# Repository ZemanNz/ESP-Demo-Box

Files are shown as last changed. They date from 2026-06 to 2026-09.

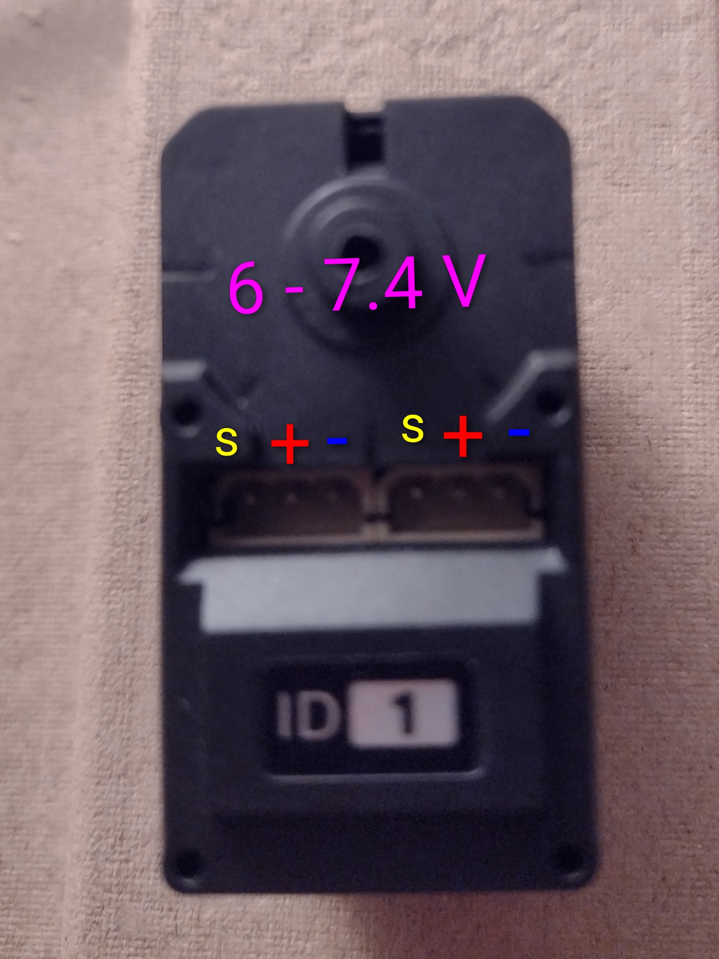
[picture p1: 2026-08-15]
documentation/ss_popis.jpg

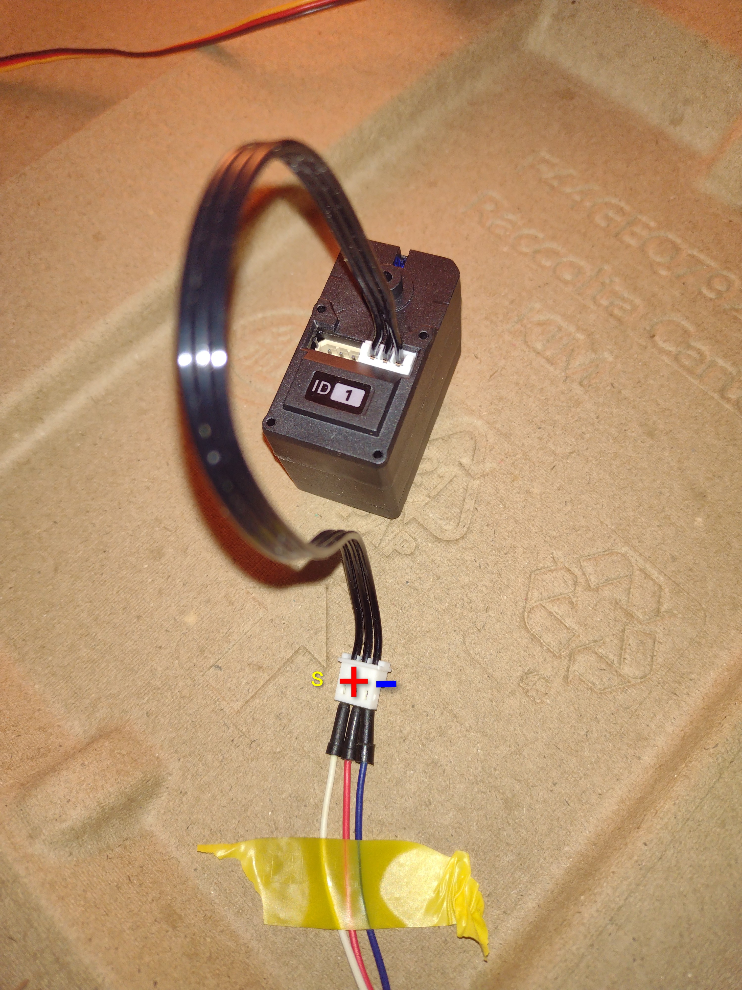
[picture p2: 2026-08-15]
documentation/zap_ss.jpg

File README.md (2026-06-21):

# ESP-Demo-Box

Tento projekt obsahuje kompletní podklady pro vývoj a konstrukci zařízení **ESP-Demo-Box**. Projekt je rozdělen do několika hlavních částí:

## Struktura projektu

- **`documentation/`**: Uživatelská a technická dokumentace k projektu.
- **`firmware/`**: Zdrojové kódy pro mikrokontroléry (PlatformIO projekty pro desky ESP32-S3).
  - **`horni_panel/`**: Firmware pro horní panel.
  - **`spodni_panel/`**: Firmware pro spodní panel.
- **`hardware/`**: Podklady pro výrobu a konstrukci.
  - **`3D/`**: 3D modely pro tisk.
  - **`Ele/`**: Schémata zapojení a plošné spoje.

## Vývoj (Firmware)

Firmware je vyvíjen v prostředí **PlatformIO** (ideálně jako rozšíření pro VS Code).

### Požadavky
- [VS Code](https://code.visualstudio.com/) s nainstalovaným rozšířením [PlatformIO IDE](https://platformio.org/platformio-ide).

### Otevření a kompilace
1. Otevřete konkrétní složku projektu ve `firmware/` (např. `horni_panel` nebo `spodni_panel`) v VS Code.
2. PlatformIO automaticky stáhne potřebné závislosti a nástroje pro ESP32-S3.
3. Pro sestavení projektu použijte tlačítko **Build** (ikonka zaškrtnutí) v dolní liště PlatformIO.
4. Pro nahrání firmwaru připojte desku přes USB a klikněte na **Upload** (ikonka šipky).

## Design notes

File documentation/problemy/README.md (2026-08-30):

# Dokumentace problémů a jejich řešení – Maturitní projekt ESP-Demo-Box

Tato složka slouží jako přehledný registr technických problémů, na které jsme narazili během vývoje firmware a hardware pro maturitní projekt ESP-Demo-Box, a detailní popis jejich řešení.

## Seznam zdokumentovaných problémů

| ID | Název problému / Téma | Oblast | Odkaz na detailní popis |
| :--- | :--- | :--- | :--- |
| **01** | Problikávání TFT displeje ST7789 při vykreslování her | Grafika / SPI displej | [Zobrazit řešení (Double Buffering)](problikavani_displeje_double_buffering.md) |
| **02** | Zarovnání paměti v binárním UART protokolu (Memory Padding) | Komunikace / Paměť | [Zobrazit řešení (#pragma pack)](01_zarovnani_pameti_pragma_pack.md) |
| **03** | Zabezpečení integrity dat a rušení od motorů (XOR Checksum) | Komunikace / EMI | [Zobrazit řešení (XOR Checksum)](02_integrita_dat_xor_checksum.md) |
| **04** | Konflikt autority řízení servomotorů v distribuovaném systému | Řízení / Robotika | [Zobrazit rozbor (Authority Race)](03_konflikt_autority_rizeni_serv.md) |
| **05** | Hybridní UART přenos (Okamžitá změna + Záchranný Heartbeat) | Komunikace / FreeRTOS | [Zobrazit řešení (Hybridní přenos)](04_hybridni_uart_prenos_heartbeat.md) |
| **06** | Oddělení datového stavu a fyzických ovladačů (Architecture) | Architektura C++ | [Zobrazit řešení (SystemState vs SensorManager)](05_oddeleni_systemstate_a_sensormanager.md) |
| **07** | Řízení periferií dolního panelu čistě přes virtuální stav | Architektura / Abstrakce | [Zobrazit řešení (Virtuální stav)](06_rizeni_dolniho_panelu_pres_virtualni_stav.md) |
| **08** | Architektura Master-Slave mezi dvěma mikrokontroléry ESP32 | Systémový návrh | [Zobrazit rozbor (Master-Slave ESP32)](07_architektura_master_slave_esp32.md) |
| **09** | Úsporný režim Light Sleep a asynchronní probouzení (Wake-up) | Power Management / HW | [Zobrazit řešení (Light Sleep)](08_usporny_rezim_light_sleep_a_wake_up.md) |
| **10** | Vkládání webu do Flash paměti (`PROGMEM`), HTTP Caching a trvalá paměť | Web / Síť / Paměť | [Zobrazit řešení (PROGMEM & HTTP Caching)](09_vkladani_webu_do_progmem_a_http_caching.md) |

---
*Všechny dokumenty obsahují detailní technické zdůvodnění, matematické a paměťové souvislosti a zdrojové kódy přímo použitelné do textové části maturitní práce.*

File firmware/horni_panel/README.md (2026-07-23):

# Horní senzorový panel – ESP32-S3 Firmware
**Maturitní projekt | ESP32-S3 DevKitC (44 pinů) | PlatformIO + Arduino Framework**

Tento projekt obsahuje plně modulární, produkčně laděný firmware pro **Horní senzorový panel** předváděcího demo boxu. Všechny moduly jsou řízeny přes konfigurační makra (`#define ENABLE_*`) v souboru `include/config.h` a běží v neblokující smyčce `loop()` s přesným časováním `millis()`.

---

## 🚀 Stav vývoje a testování
> **Dnešní stav (23. 7. 2026):**  
> Všechny moduly byly odzkoušeny, zkompilovány a **úspěšně nahrány a ověřeny na reálném hardwaru ESP32-S3 DevKitC**. Systém běží stabilně, bez pádu procesoru i bez zásahů Task Watchdog Timeru (`TG1WDT_SYS_RST`).

---

## 🛠️ Funkcionalita a součinnost modulů

1. **Barevná interakce (TCS34725 ➔ WS2812B LED pásek)**:
   - Senzor **TCS34725** načítá RGB složky přiloženého objektu.
   - Pásek **WS2812B (8 RGB LED)** dynamicky zrcadlí naměřenou barvu v reálném čase.
2. **Duální I2C sběrnice (Vyřešení kolize adres 0x29)**:
   - `I2C_0` (Wire, SDA: 8, SCL: 9): Řídí **LSM6DS3** (0x6A), **LCD1602** (0x27) a **VL53L0X** (0x29).
   - `I2C_1` (Wire1, SDA: 5, SCL: 6): Samostatná sběrnice pro **TCS34725** (0x29) zamezuje konfliktům adres.
3. **Měření vzdálenosti a překážek**:
   - **VL53L0X**: Přesné laserové měření vzdálenosti v milimetrech přes I2C_0.
   - **HC-SR04**: Ultrazvukové měření vzdálenosti v centimetrech (TRIG = GPIO 4, ECHO = GPIO 18).
   - **IR Senzor 1**: Digitální detekce překážek na GPIO 38 (LOW = detekce).
4. **Zobrazení dat**:
   - **2.8" TFT ST7789** (SPI): Střídá 3 grafické obrazovky (Senzory, Vzdálenost, Uptime).
   - **LCD 1602 I2C**: Zobrazuje aktuální teplotu a vlhkost ze senzoru DHT11.
   - **74HC595 Sedmisegment**: Bit-banging čítač 0–999 na 3 číslicích (DATA = 15, CLK = 16, LATCH = 17).
5. **Orientační senzor**:
   - **LSM6DS3**: Gyroskop a akcelerometr s automatickou klidovou kalibrací offsetu při startu (výpočet Roll, Pitch, Yaw).
6. **Zvuková a vizuální odezva**:
   - **Pasivní bzučák**: Zvuková znělka při startu + krátké pípnutí každých 5 sekund.
   - **DHT11**: Teplotní a vlhkostní senzor na GPIO 3.

---

## 📌 Kompletní mapa zapojení pinů (ESP32-S3)

| Zařízení / Modul | Signál | ESP32-S3 GPIO | Poznámka |
| :--- | :--- | :--- | :--- |
| **DHT11** | DATA | **GPIO 3** | Teplota & Vlhkost (4k7 pull-up) |
| **HC-SR04** | TRIG | **GPIO 4** | Ultrazvuk Trigger |
| **HC-SR04** | ECHO | **GPIO 18** | Ultrazvuk Echo *(mimo USB piny)* |
| **IR Senzor 1** | OUT | **GPIO 38** | Detekce překážky *(mimo Octal Flash)* |
| **WS2812B** | DATA | **GPIO 42** | 8 RGB LED *(Adafruit_NeoPixel)* |
| **Bzučák** | Vstup | **GPIO 7** | Pasivní bzučák |
| **74HC595** | DS (DATA) | **GPIO 15** | Sedmisegmentová sériová data |
| **74HC595** | SH_CP (CLK)| **GPIO 16** | Sedmisegmentové hodiny |
| **74HC595** | ST_CP (LATCH)| **GPIO 17** | Sedmisegmentový Latch |
| **TFT 2.8"** | CS | **GPIO 10** | Chip Select |
| **TFT 2.8"** | SDI (MOSI) | **GPIO 11** | Hardware SPI Data |
| **TFT 2.8"** | SCK | **GPIO 12** | Hardware SPI Clock |
| **TFT 2.8"** | DC | **GPIO 13** | Data / Command |
| **TFT 2.8"** | RESET | **GPIO 14** | Reset displeje |
| **TFT 2.8"** | LED | **GPIO 21** / 3.3V | Podsvícení |
| **I2C_0 (Wire)** | SDA / SCL | **GPIO 8 / GPIO 9** | LSM6DS3, LCD1602, VL53L0X |
| **I2C_1 (Wire1)**| SDA / SCL | **GPIO 5 / GPIO 6** | TCS34725 (0x29) |
| **Fotorezistory**| IN1 / IN2 | **GPIO 1 / GPIO 2** | Analogové fotorezistory |
| **Tlačítka** | BTN1 / BTN2 | **GPIO 47 / GPIO 48** | INPUT_PULLUP |

### ⚠️ Vyhrazené piny (Nepoužívat pro I/O!):
- **GPIO 19, 20**: Vnitřně vyhrazeno pro rozhraní **USB D- / D+**.
- **GPIO 33, 34, 35, 36, 37**: Vnitřně vyhrazeno pro paměťovou sběrnici **Octal Flash / OPI PSRAM** na ESP32-S3 N16R8.

---

## ⚙️ Kompilace a nahrání (PlatformIO)

 Sestavení projektu:
```bash
pio run -e demo_panel
```

 Nahrání do ESP32-S3:
```bash
pio run -e demo_panel -t upload --upload-port /dev/ttyUSB0
```

 Sériový monitor (115200 baud):
```bash
pio device monitor -b 115200
```

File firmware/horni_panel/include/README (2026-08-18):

# Horní senzorový panel – Zapojení hardwaru
**ESP32-S3 DevKitC (44 pinů) | Maturitní projekt**

Tento soubor obsahuje **aktuální a přesnou** mapu zapojení všech modulů.
Všechny definice pinů odpovídají souboru `config.h` a `demo_panel.cpp`.

---

## Povolení / zakázání modulů

V souboru `config.h` lze jednotlivé moduly zapínat nebo vypínat odkomentováním/zakomentováním příslušného `#define ENABLE_*`.

---

## 1. Digitální senzory

| Zařízení | ESP32 GPIO | Poznámka / Nastavení |
|---|---|---|
| **DHT11 DATA** | GPIO **3** | Teplota & vlhkost (4k7 pull-up na 3.3 V) |
| **HC-SR04 TRIG** | GPIO **4** | Ultrazvuk – Trigger pulz (10 µs HIGH) |
| **HC-SR04 ECHO** | GPIO **18**  | Ultrazvuk – Echo vstup (3.3 V logic) |
| **IR Senzor 1**  | GPIO **38**  | Digitální detekce překážky (LOW = detekce)  |
| **LSM6DS3 INT1** | GPIO **45**  | Přerušení akcelerometru pro probuzení otřesem (GPIO 45) |
| **Tlačítko 1** | GPIO **47**  | INPUT_PULLUP (GND při stisku) |
| **Tlačítko 2** | GPIO **48**  | INPUT_PULLUP (Reset desky) |

---

## 2. Analogové vstupy

| Zařízení | ESP32 GPIO | Poznámka |
|---|---|---|
| Fotorezistor 1 | GPIO **1** | ADC1, napěťový dělič  |
| Fotorezistor 2 | GPIO **2** | ADC1, napěťový dělič  |

---

## 3. Výstupy & LED

| Zařízení | ESP32 GPIO | Poznámka |
|---|---|---|
| **Pasivní bzučák**| GPIO **7** | tone() – tranzistorový spínač |
| **LED 1** | GPIO **39**| Rezistor 220 Ω |
| **LED 2** | GPIO **40**| Rezistor 220 Ω |
| **LED 3** | GPIO **41**| Rezistor 220 Ω |
| **WS2812B DATA**  | GPIO **42**| 8 RGB LED pásek (Adafruit_NeoPixel) |

---

## 4. 74HC595 – Sedmisegmentový displej (3 číslice, bit-banging)

Displej se Společnou Anodou (`SEG_COMMON_ANODE = true`).

| Signál | HC595 pin | ESP32 GPIO  |
|---|---|---|
| DS (DATA) | pin 14 | GPIO **15** |
| SH_CP (CLK) | pin 11 | GPIO **16** |
| ST_CP (LATCH) | pin 12 | GPIO **17** |
| OE (Enable) | pin 13 | GND |
| MR (Reset) | pin 10 | 3.3 V |

---

## 5. TFT 2.8" displej (ILI9341 / ST7789, SPI)

Knihovna: `Adafruit_ST7789` | Rozlišení: 240×320 (landscape 320×240)

Presné názvy pinů podle potisku na displeji (shodné s `examples/2.8_tft_display/README.md`):

| Displej Pin (Potisk) | ESP32-S3 GPIO | Popis signálu |
| --- | --- | --- |
| **VCC** | `5V` | Napájení displeje |
| **GND** | `GND` | Společná zem |
| **CS** | `GPIO 10` | Chip Select (výběr SPI čipu) |
| **RESET** | `GPIO 14` | Reset displeje |
| **DC** | `GPIO 13` | Data / Command (příkazový signál) |
| **SDI (MOSI)** | `GPIO 11` | Hardware SPI Data (Master Out Slave In) |
| **SCK** | `GPIO 12` | Hardware SPI Clock (hodiny) |
| **LED** | `3.3V` / `GPIO 21` | Podsvícení displeje (trvale 3.3 V nebo GPIO 21) |
| **SDO (MISO)** | *Nezapojeno*  | MISO / Dotyková vrstva (nevyužito) |

---

## 6. I2C sběrnice (Dvou-sběrnicový systém pro zamezení kolizí)

### I2C_0 – Hlavní sběrnice (Wire)
| Zařízení | Adresa | ESP32 GPIO |
|---|---|---|
| LSM6DS3 (gyro) | 0x6A | SDA: **8**, SCL: **9** |
| LCD 1602 (PCF8574)| 0x27 | SDA: **8**, SCL: **9** |
| VL53L0X (laser) | 0x29 | SDA: **8**, SCL: **9** |

### I2C_1 – Sekundární sběrnice (Wire1)
Důvod: TCS34725 má adresu 0x29, která by kolidovala s VL53L0X.
| Zařízení | Adresa | ESP32 GPIO |
|---|---|---|
| TCS34725 (barva)  | 0x29 | SDA: **5**, SCL: **6** |

---

## 7. UART1 – Komunikace s druhým ESP32

| Signál | ESP32 GPIO  |
|---|---|
| TX (výstup) | GPIO **17** |
| RX (vstup)  | GPIO **18** |

*(Baudrate: 115200, 8N1. Pozn: GPIO 17/18 lze sdílet pokud je UART1 vypnutý).*

---

## 8. Kompletní tabulka GPIO pinů (Quick Reference)

| GPIO | Připojené zařízení / Funkce | GPIO | Připojené zařízení / Funkce |
|---|---|---|---|
| **1**| Fotorezistor 1 | **21**| TFT podsvícení (BL) |
| **2**| Fotorezistor 2 | **38**| IR Senzor 1 |
| **3**| DHT11 DATA | **39**| LED 1 |
| **4**| HC-SR04 TRIG | **40**| LED 2 |
| **5**| I2C1 SDA (TCS34725) | **41**| LED 3 |
| **6**| I2C1 SCL (TCS34725) | **42**| WS2812B RGB pásek |
| **7**| Bzučák | **43**| UART0 TX (Serial Monitor) |
| **8**| I2C0 SDA | **44**| UART0 RX (Serial Monitor) |
| **9**| I2C0 SCL | **47**| Tlačítko 1 |
| **10**| TFT CS (Chip Select) | **48**| Tlačítko 2 / Reset |
| **11**| TFT SDI / MOSI (Data) | | |
| **12**| TFT SCK (Hodiny) | | |
| **13**| TFT DC (Data/Command) | | |
| **14**| TFT RESET | | |
| **15**| 74HC595 DATA | | |
| **16**| 74HC595 CLK | | |
| **17**| 74HC595 LATCH / UART1 TX | | |
| **18**| HC-SR04 ECHO / UART1 RX | | |

---

## ⚠️ Důležitá varování pro ESP32-S3 N16R8:

1. **GPIO 19 a 20 (NEPOUŽÍVAT)**: Vnitřně vyhrazeny pro USB D- a D+. Použití pro běžné I/O způsobí zamrznutí nebo zablokování nahrávání.
2. **GPIO 33, 34, 35, 36, 37 (NEPOUŽÍVAT)**: Vnitřně vyhrazeny pro Octal Flash/PSRAM paměťovou sběrnici. Příkaz `pinMode()` na těchto pinech způsobí okamžitý pády/reset procesoru (`TG1WDT_SYS_RST`).

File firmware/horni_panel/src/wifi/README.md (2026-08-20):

# Jednoduchý průvodce Wi-Fi a Webem (ESP-Demo-Box)

Tento návod ti **lidsky, jednoduše a názorně** vysvětlí, jak celá bezdrátová část v našem Demo-Boxu funguje. Nemusíš být síťový expert – vše je vysvětleno na praktických přirovnáních a na reálném fungování kódu krok za krokem.

---

## 1. Co to celé dělá a jak to funguje v praxi?

Představ si, že přijdeš k hotovému Demo-Boxu:
1. **ESP32 se zapne** a začne se chovat jako malý **Wi-Fi router** (vysílá vlastní Wi-Fi síť s názvem `ESP-Demo-Box`).
2. Ty vezmeš telefon a **fotoaparátem naskenuješ QR kód** na krabičce.
3. Mobil se **bez zadávání hesla připojí**.
4. Během vteřiny mobilu **automaticky vyskočí okno s naším webem** (díky funkci *Captive Portal* – stejně jako když se připojuješ na Wi-Fi v hotelu nebo ve vlaku).
5. Na mobilu vidíš **živé hodnoty ze všech senzorů** (teplota, vzdálenosti, gyroskop, tlačítka) a můžeš prstem **hýbat servy, motorem, rozsvěcet LEDky nebo přepínat hry na displeji**.

---

## 2. Kde co běží? (Backend vs. Frontend)

Aby ses v tom neztratil, musíme si rozdělit svět na dvě části:

```
+------------------------------------+          +------------------------------------+
|       ESP32-S3 (BACKEND)           |          |     MOBILNÍ TELEFON (FRONTEND)     |
|                                    |          |                                    |
| - Běží v čipu v krabičce (Core 0)  |  Wi-Fi   | - Běží v prohlížeči v mobilu       |
| - Kód: WebManager.h a .cpp         | <======> | - Kód: HTML, CSS, JavaScript       |
| - Nemá webový prohlížeč!           | WebSocket| - Zobrazuje tlačítka a barvy       |
| - Stará se o senzory, serva a motory|         | - Počítá dotyky prstů uživatele    |
+------------------------------------+          +------------------------------------+
```

1. **Backend (ESP32 / `WebManager.cpp`):**
   * Běží fyzicky v mikrokontroléru ESP32-S3 na **Core 0**.
   * Nemá žádný prohlížeč ani vykreslovací grafickou kartu pro web.
   * Jeho úkolem je vysílat Wi-Fi signál, přijímat příkazy a starat se o hardware (číst fyzické senzory, hýbat servy a ovládat motory).

2. **Frontend (Mobilní telefon / `index.html`, `style.css`, `script.js`):**
   * Webový kód je sice zkompilovaný a uložený ve Flash paměti ESP32 (`WebPages.h`), ale **ESP32 ho sama nespouští**.
   * Jakmile se mobil připojí, ESP32 pošle tento text přes Wi-Fi do mobilu.
   * **Teprve webový prohlížeč v mobilu** (Safari nebo Chrome) tento kód zpracuje, nakreslí hezká tlačítka a spustí JavaScript. Všechny animace a barvy tak počítá procesor tvého telefonu!

---

## 3. Hlavní pojmy a síťové základy vysvětlené „po lopatě“

### 🚪 A) Co je to HTTP port (Port 80) a DNS port (Port 53)?
Představ si IP adresu (`192.168.4.1`) jako **adresu panelového domu**:
* Aby pošťák věděl, do kterých konkrétních dveří v domě má jít, potřebuje **číslo bytu = PORT**.
* Na jedné IP adrese může běžet více různých síťových služeb, a každá naslouchá u svých vlastních dveří:
  * **Port 80 (HTTP):** Dveře vyhrazené pro webové stránky. Když do prohlížeče napíšeš IP adresu, prohlížeč automaticky klepe na dveře číslo 80.
  * **Port 53 (DNS):** Dveře vyhrazené pro překladač doménových jmen.

---

### 🌐 B) Co je to DNS server (Port 53) a jak funguje Captive Portal?
* **Jak funguje běžný internet:** Když v mobilu napíšeš `seznam.cz`, mobil se zeptá DNS serveru na portu 53: *"Jaká je IP adresa pro seznam.cz?"* DNS server odpoví: `77.75.77.222`.
* **Náš trik (Fake DNS na ESP32):** Naše ESP32 má spuštěný vlastní DNS server na portu 53 (`dnsServer.start(53, "*", "192.168.4.1")`).
* Když se mobil připojí k síti `ESP-Demo-Box`, okamžitě na pozadí zkouší posílat DNS dotazy na internet (zkoumá, zda funguje síť).
* Náš DNS server na **jakýkoliv dotaz z mobilu odpoví: `192.168.4.1`**.
* Mobilní telefon si myslí: *"Aha, tohle je síť v hotelu nebo ve vlaku, kde se musím nejprve přihlásit!"* a **sám automaticky vytáhne okno s naším webem na displej**. Uživatel tak nemusí nikam psát žádnou IP adresu.

---

### ⚡ C) Co je to WebSocket a jak funguje jeho nastavení (`setupWebSocket`)?
Rozdíl mezi běžným webem a WebSocketem:
1. **Běžný web (HTTP):** Mobil klepe na dveře portu 80, požádá o soubor, ESP32 mu ho podá a dveře se zabouchnou. Kdybychom takhle chtěli živá data ze senzorů, mobil by musel klepat 10× za sekundu.
2. **WebSocket (`ws://192.168.4.1/ws`):** Mobil a ESP32 se dohodnou, že po otevření webu **nechají dveře dokořán a vytvoří mezi sebou přímé potrubí**.

**Jak funguje nastavení v kódu C++ (`WebManager.cpp`):**
```cpp
void WebManager::setupWebSocket() {
    ws.onEvent([this](AsyncWebSocket *server, AsyncWebSocketClient *client, 
                      AwsEventType type, void *arg, uint8_t *data, size_t len) {
        this->onWebSocketEvent(server, client, type, arg, data, len);
    });
    server.addHandler(&ws);
}
```
* Tato funkce říká webovému serveru: *"Kdykoliv se na adrese `/ws` cokoliv stane (mobil se připojí, odpojí nebo pošle příkaz), okamžitě zavolej naši funkci `onWebSocketEvent`!"*

---

### 📦 D) Co je to JSON a jak si mobil s ESP32 povídá?
Data mezi mobilem a ESP32 posíláme v jednoduchém textovém formátu **JSON**:

* **Když ESP32 posílá data do mobilu (Telemetrie):**
  ```json
  {"t": 23.5, "h": 48.2, "laser": 150, "led1": true, "mode": 2}
  ```
  *(Znamená to: Teplota 23.5 °C, vlhkost 48.2 %, vzdálenost 150 mm, LED1 svítí, běží mód 2).*

* **Když mobil posílá povel do ESP32 (Ovládání):**
  ```json
  {"cmd": "setServo", "val": 120}
  ```
  *(Znamená to: Nastav servo na 120 stupňů).*

---

### 🧠 E) Proč má ESP32 dvě jádra a proč Wi-Fi běží na Core 0?
Čip **ESP32-S3 má dva nezávislé procesory (Core 0 a Core 1)**:
* **Core 1 (Hry a Displej):** Neustále na plný výkon kreslí grafiku na 2.8" displej (hry Snake, Flappy Bird, vykreslování textu).
* **Core 0 (Wi-Fi):** Stará se o rádiové vlny, síť a web.
* **Proč je to geniální?** Kdyby obojí běželo na jednom jádře, pokaždé, když by mobil stahoval data, displej by se viditelně sekl nebo by kleslo FPS. Takhle běží obě jádra vedle sebe a displej je 100% plynulý.

---

### 🚦 F) Co je to Mutex? (Semafor pro paměť)
* Obě jádra procesoru potřebují sahat na stejná data (např. teplotu ze senzoru nebo polohu joysticku).
* Aby se nestalo, že Core 0 čte teplotu zrovna v polovině zápisu z Core 1 (což by mohlo čip shodit), používáme v souboru `SystemState.h` tzv. **Mutex** (ze slov *Mutual Exclusion*).
* Funguje to jako **semafor na jednokolejné trati**: Než jádro sáhne do paměti, rozsvítí červenou. Druhé jádro počká zlomek mikrosekundy, a jakmile první skončí, semafor se uvolní.

---

### 🛡️ G) Co je to Throttle v JavaScriptu?
* Když na mobilu prstem rychle posouváš jezdec serva nebo motoru z 0 na 180, mobil by vygeneroval klidně 100 zpráv za vteřinu.
* V souboru `script.js` máme funkci `throttle`: ta propustí maximálně 20 zpráv za sekundu (jednu každých 50 ms).
* Pro lidské oko je to naprosto okamžité a plynulé, ale zabrání to zahlcení Wi-Fi fronty v ESP32.

---

### 💾 H) Proč máme web v `WebPages.h` (PROGMEM)?
* V Arduinu se webové soubory často nahrávají do souborového systému *LittleFS* (což vyžaduje speciální nahrávací krok přes *Upload Filesystem Image*).
* My jsme HTML, CSS a JS vložili přímo do souboru `WebPages.h` pomocí klíčového slova `PROGMEM`.
* **Výsledek:** Celý web se zkompiluje přímo do programu. Stačí zmáčknout klasický **Upload** v PlatformIO a nahraje se vše najednout. Navíc se neubírá ani bajt z operační paměti RAM.

---

## 4. Jak to celé funguje dohromady? (Kompletní příklad krok za krokem)

Pojďme si projít kompletní životní cyklus aplikace od stisknutí tlačítka napájení na krabičce až po otočení servomotoru:

```mermaid
sequenceDiagram
    autonumber
    participant ESP_C0 as ESP32 Core 0 (Wi-Fi)
    participant State as SystemState (Paměť)
    participant Phone as Mobil (Prohlížeč)
    participant ESP_C1 as ESP32 Core 1 (Pohony)

    Note over ESP_C0: 1. Start systému
    ESP_C0->>ESP_C0: Spustí SoftAP "ESP-Demo-Box", DNS (Port 53) a WebServer (Port 80)
    
    Note over Phone: 2. Pripojení & Captive Portal
    Phone->>ESP_C0: Naskenuje QR & připojí se k Wi-Fi
    Phone->>ESP_C0: DNS dotaz na Port 53 -> Fake DNS odpoví "192.168.4.1"
    ESP_C0-->>Phone: Vrátí HTML, CSS a JS z Flash paměti (WebPages.h)
    
    Note over Phone: 3. Otevření WebSocketu
    Phone->>ESP_C0: Připojí se k WebSocketu ws://192.168.4.1/ws
    
    loop Každých 100 ms (Telemetrie)
        ESP_C0->>State: getSensorData() (Přes Mutex)
        ESP_C0-->>Phone: Pošle JSON telemetrii {"t":23.5, "laser":120, ...}
        Phone->>Phone: script.js přepíše čísla v HTML na displeji mobilu
    end

    Note over Phone: 4. Povel z mobilu (Pohyb servem)
    Phone->>Phone: Uživatel posune slider serva na 90° -> zavolá se onServoChange(90)
    Phone->>ESP_C0: Pošle WebSocket JSON {"cmd":"setServo", "val":90}
    ESP_C0->>ESP_C0: handleClientMessage() rozbalí JSON a zjistí cmd=="setServo"
    ESP_C0->>State: updateServo(90) (Zaznamená 90° přes Mutex)
    ESP_C1->>State: Přečte 90° ze SystemState
    ESP_C1->>ESP_C1: Fyzicky otočí servomotor na krabičce o 90°!
```

### Krok 1: Zapnutí ESP32 (Start Backend částí)
1. Funkce `setup()` v `main.cpp` vytvoří FreeRTOS úlohu `Task_WiFi_Web` připnutou na **Core 0**.
2. Úloha zavolá `webManager.begin(&globalState)`.
3. `begin()` přepne Wi-Fi na Access Point `ESP-Demo-Box`, spustí DNS server na portu 53, nastaví webové směrování (HTTP port 80) a zapne WebSocket na `/ws`.
4. Úloha vstoupí do nekonečného cyklu `for (;;)`, kde neustále dokola volá `webManager.update()`.

### Krok 2: Připojení mobilu a načtení vzhledu (Frontend)
1. Uživatel namíří fotoaparát na QR kód a mobil se připojí k síti `ESP-Demo-Box`.
2. Mobil zkouší na pozadí zjistit internet -> náš DNS server v `webManager.update()` odchytí dotaz na portu 53 a vrátí IP `192.168.4.1`.
3. Mobil vyvolá okno a pošle HTTP požadavek na port 80 (`GET /`).
4. Funkce v `setupRoutes()` vezme text `INDEX_HTML` z Flash paměti (`WebPages.h`) a pošle ho do mobilu. Mobil si pak stejným způsobem stáhne `style.css` a `script.js`.
5. V prohlížeči telefonu se zobrazi tmavé rozhraní s kartami a tlačítky.

### Krok 3: Živá komunikace (WebSocket & Telemetrie)
1. Po načtení stránky sputí `script.js` v mobilu funkci `initWebSocket()` a otevře trvalý kanál na `ws://192.168.4.1/ws`.
2. V ESP32 zachytí událost metoda `ws.onEvent` s typem `WS_EVT_CONNECT`.
3. Při dalším průchodu smyčky `webManager.update()` vidí ESP32 `ws.count() > 0`. Každých 100 ms zavolá `broadcastTelemetry()`.
4. `broadcastTelemetry()` si bezpečně přes Mutex vytáhne snímek dat z `globalState.getSensorData()`, zabalí ho do JSONu a rozesle ho do mobilu.
5. V mobilu přijme zprávu funkce `ws.onmessage`, zavolá `handleTelemetry(d)` a okamžitě přepíše čísla na obrazovce (teplota, vzdálenosti, gyroskop).

### Krok 4: Povel z mobilu (Pohyb servem)
1. Uživatel na mobilu posune slider serva na 90°.
2. Událost `oninput` v `index.html` zavolá v `script.js` funkci `onServoChange(90)`.
3. Funkce `onServoChange` přes omezovač `throttle` zavolá `sendCmd('setServo', {val: 90})`.
4. Mobil pošle přes WebSocket textovou zprávu `{"cmd":"setServo","val":90}`.
5. V ESP32 zachytí událost `ws.onEvent` s typem `WS_EVT_DATA` a předá ji do `handleClientMessage()`.
6. `handleClientMessage()` rozbalí JSON, zjistí `cmd == "setServo"` a zavolá `pState->updateServo(90)`.
7. Vlákno obsluhující pohony na **Core 1** si přečte novou hodnotu 90° ze `SystemState` a fyzicky otočí servomotor na krabičce!

---

## 5. Tahák k maturitní obhajobě (Otázky a odpovědi)

#### Otázka 1: *„Kde fyzicky běží kód webové stránky a kde kód síťového serveru?“*
> **Tvoje odpověď:** *„Kód síťového serveru běží na mikrokontroléru ESP32-S3 na jádře Core 0 v jazyce C++. Kód webové stránky (HTML, CSS a JavaScript) je sice zkompilován ve Flash paměti ESP32, ale po připojení se pošle do mobilního telefonu a spouští se v prohlížeči mobilu. Výpočet animací a vykreslení tlačítek tak provádí procesor telefonu.“*

#### Otázka 2: *„Co je to HTTP port 80 a DNS port 53?“*
> **Tvoje odpověď:** *„IP adresa určuje zařízení v síti. Porty jsou jako konkrétní dveře pro jednotlivé služby. Port 80 je standardní dveře pro webové stránky (HTTP). Port 53 slouží pro DNS překladač domén. Náš DNS server na portu 53 zachytí jakýkoliv dotaz mobilu a přesměruje ho na naši webovou stránku na portu 80 (Captive Portal).“*

#### Otázka 3: *„Jak funguje WebSocket a v čem je lepší než HTTP REST API?“*
> **Tvoje odpověď:** *„HTTP spojení vyžaduje pro každý požadavek sestavení TCP spojení a odeslání HTTP hlaviček, což by při rychlém posílání dat zahltilo síť i procesor. WebSocket po úvodním stáhnutí stránek naváže jedno trvalé obousměrné TCP spojení s minimální režijní zátěží (2 bajty na paket). Umožňuje přenášet telemetrii 10× za sekundu a ihned přijímat povely.“*

#### Otázka 4: *„Jak je vyřešen běh na dvou jádrech ESP32-S3?“*
> **Tvoje odpověď:** *„Využívám operační systém reálného času FreeRTOS. Na Core 1 běží grafika displeje a herní smyčky, zatímco celou Wi-Fi, Captive Portal a WebSockets obsluhuje samostatná úloha na Core 0. Přístup k datům je zabezpečen pomocí Mutexu, aby nedošlo k souběhu.“*

#### Otázka 5: *„Jak šetříte paměť RAM v ESP32?“*
> **Tvoje odpověď:** *„Webové soubory jsou uloženy ve Flash paměti programu přes makro PROGMEM. Pro JSON zprávy používám ArduinoJson v7 s pevnou alokací na zásobníku (stack), takže nedochází k fragmentaci paměti haldy (heap). Navíc, pokud není připojen žádný klient, generování JSONu se úplně přeskakuje.“*

#### Otázka 6: *„Jak to, že má ESP32 anténku dlouhou jen cca 3 cm, když vlnová délka 2.4 GHz je 12.4 cm?“*
> **Tvoje odpověď:** *„Anténa nemusí mít délku celé vlnové délky. Pro nejlepší rezonanci se používá čtvrtvlnný rezonátor (lambda / 4). Když spočítáme čtvrtinu z 12.4 cm: 12.4 / 4 = 3.1 cm! Přesně 3.1 cm dlouhá měděná cestička je fyzikálně ideální rezonátor pro frekvenci 2.4 GHz.“*

#### Otázka 7: *„Nezinterferují vlny mezi sebou, když je anténa na plošném spoji zohýbaná (meandrovaná)?“*
> **Tvoje odpověď:** *„Ne, zohýbání (tzv. Meander Line Antenna) je přesně matematicky navržené tak, aby se 3.1 cm dlouhá anténa vešla na malou desku. Vzdálenosti ohybů jsou spočítané tak, aby se vyzařovaná elektromagnetická pole z protilehlých ramen nepůsobila destruktivně, ale naopak se konstruktivně sčítala.“*

#### Otázka 8: *„Když elektromagnetická vlna letí rychlostí světla, jak ji mobil dokáže dekódovat?“*
> **Tvoje odpověď:** *„Přijímač v mobilu neposuzuje rychlost letu vlny prostorem. Vlna po dopadu na anténu mobilu indukuje střídavý elektrický proud kmitající na frekvenci 2.4 GHz. Vysokorychlostní Wi-Fi modem v mobilu pak dekóduje posuny fáze a výšku těchto kmitů přímo v reálném čase.“*

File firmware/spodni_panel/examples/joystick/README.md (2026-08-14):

# Příklad: Analogový Joystick (Osa X, Y a tlačítko SW)

Tento příklad demonstruje čtení dvouosého analogového joysticku (např. modul **KY-023** nebo **HW-504**) s integrovaným spínacím tlačítkem, připojeného ke spodní desce ESP32-WROOM.

---

## Hardwarové zapojení

| Pin na Joysticku | Funkce | ESP32 DevKit Pin | Popis / Poznámka |
| :--- | :--- | :--- | :--- |
| **GND** | Zem | **GND** | Společná zem |
| **+5V / VCC** | Napájení | **3.3V** | Doporučeno 3.3V (aby analogový výstup nepřesáhl rozsah ADC) |
| **VRx / X** | Osa X | **GPIO 36 (VP)** | Analogový vstup osy X (ADC1_CHANNEL_0) |
| **VRy / Y** | Osa Y | **GPIO 39 (VN)** | Analogový vstup osy Y (ADC1_CHANNEL_3) |
| **SW / KEY** | Tlačítko | **GPIO 18** | Digitální vstup s interním PULL-UP (spíná proti GND) |

> **💡 Poznámka k pinům VP a VN:**  
> Na vývojové desce ESP32 jsou piny GPIO 36 a GPIO 39 označeny jako **VP** a **VN**. Jsou to čistě analogové vstupní piny převodníku ADC1 s minimálním rušením, ideální pro přesné čtení joysticku.

---

## Jak to funguje
1. **Analogové čtení (ADC)**: Funkce `analogRead()` vrací hodnotu v rozsahu **0 až 4095** (kde 0 odpovídá 0 V a 4095 odpovídá napětí 3.3 V). Ve klidové středové poloze je hodnota přibližně **2048**.
2. **Přepočet na procenta**: Pomocí funkce `map()` se naměřená hodnota 0–4095 přepočítává na relativní vychýlení v rozsahu **-100 % až +100 %**.
3. **Tlačítko (SW)**: Pin GPIO 18 je nastaven s interním pull-up rezistorem (`INPUT_PULLUP`). Při stisknutí páčky joysticku dolů se spínač sepne proti GND a hodnota přečtená pomocí `digitalRead()` klesne na `LOW`.

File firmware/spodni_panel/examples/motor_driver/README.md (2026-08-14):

# Příklad: Řízení DC Motoru (PWM regulace)

Tento příklad demonstruje jednokanálovou regulaci otáček a výkonu stejnosměrného (DC) motoru nebo jiné PWM zátěže (např. výkonová LED, topné těleso) pomocí tranzistorového/MOSFET budiče připojeného ke spodní desce ESP32-WROOM.

---

## Hardwarové zapojení

| Vývod na Budiči motoru | Funkce | ESP32 DevKit Pin | Poznámka |
| :--- | :--- | :--- | :--- |
| **PWM / IN / Signál** | Vstup pro řízení | **GPIO 25** | Výstupní PWM pin |
| **GND** | Zem | **GND** | Společná zem (musí být propojena s ESP32) |
| **V+ / Power** | Zdroj napájení | **Externí zdroj** | Napájení motoru (dle jeho jmenovitého napětí) |

> **⚠️ Důležité upozornění pro napájení:**  
> Nikdy nepřipojujte DC motor přímo na výstupní GPIO pin ESP32! Výstupní piny mikrokontroléru snesou maximální proud 12 mA až 40 mA, zatímco motory odebírají stovky mA až jednotky Ampér. Vždy použijte odpovídající budič motoru (např. MOSFET modul L298N, DRV8833, IRF520 nebo tranzistorový spínač).

---

## Jak to funguje
1. **Pulzně-šířková modulace (PWM)**: Kód využívá vestavěnou funkci Arduino frameworku `analogWrite(25, duty)`.
2. **Rozsah střídy (Duty Cycle)**: Hodnota `duty` nabývá hodnot **0 až 255**:
   - `0` = 0 % střída (trvale vypnuto / 0 V)
   - `128` = 50 % střída (poloviční výkon)
   - `255` = 100 % střída (plný výkon / napájecí napětí)
3. **Plynulý náběh (Ramp-Up/Ramp-Down)**: V hlavní smyčce program postupně zvyšuje střídu v cyklu `for`, čímž docílí plynulého rozběhu motoru bez proudových nárazů.

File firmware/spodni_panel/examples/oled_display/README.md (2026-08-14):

# Příklad: 0.96" OLED Displej (SSD1306, I2C 128x64 px)

Tento příklad demonstruje připojení a grafické ovládaní monohromatického 0.96" OLED displeje s integrovaným řadičem **SSD1306** přes I2C sběrnici ke spodní desce ESP32-WROOM.

---

## Hardwarové zapojení

| Pin na OLED Displeji | Funkce | ESP32 DevKit Pin | Poznámka |
| :--- | :--- | :--- | :--- |
| **GND** | Zem | **GND** | Společná zem |
| **VCC** | Napájení | **3.3V** | Napájení 3.3V |
| **SDA** | Sériová data I2C | **GPIO 21** | Datová linka I2C sběrnice |
| **SCL** | Hodiny I2C | **GPIO 22** | Hodinová linka I2C sběrnice |

---

## Použité knihovny
- **Adafruit SSD1306** (`adafruit/Adafruit SSD1306`)
- **Adafruit GFX Library** (`adafruit/Adafruit GFX Library`)
- **Adafruit BusIO** (`adafruit/Adafruit BusIO`)

Všechny knihovny se automaticky spravují a stahují pomocí PlatformIO.

---

## Jak to funguje
1. **Inicializace I2C**: V `setup()` se inicializuje sběrnice `Wire.begin(21, 22)` na výchozích pinech spodního panelu.
2. **Bufferovaný vykreslovací režim**: Knihovna Adafruit GFX udržuje celý obrazový rámec v paměti RAM mikrokontroléru (128 × 64 bitů = 1 KB RAM). Všechny kreslicí příkazy jako `drawFastHLine()`, `drawRect()`, `fillRect()`, `setCursor()` a `print()` kreslí do tohoto vnitřního vyrovnávacího bufferu.
3. **Odeslání na displej**: Zavoláním příkazu `display.display()` se celý buffer najednou přenese přes I2C do řadiče SSD1306, což zajišťuje plynulý obraz bez blikání.

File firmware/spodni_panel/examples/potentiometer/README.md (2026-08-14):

# Příklad: Analogový Potenciometr

Tento příklad demonstruje měření polohy a napětí z běžného otočného potenciometru (např. 10kΩ) připojeného ke spodnímu panelu s ESP32-WROOM.

---

## Hardwarové zapojení

| Vývod na Potenciometru | Funkce | ESP32 DevKit Pin | Poznámka |
| :--- | :--- | :--- | :--- |
| **Krajní vývod 1** | Zem | **GND** | Společná zem |
| **Prostřední vývod** | Jezdec / Signál | **GPIO 34** | Analogový vstup (ADC1_CHANNEL_6) |
| **Krajní vývod 2** | Napájení | **3.3V** | Napájení 3.3V |

---

## Jak to funguje
1. **Otočný dělíč napětí**: Potenciometr funguje jako nastavitelný odporový dělič napětí. Otáčením hřídelky plynule měníme napětí na prostředním pinu od 0 V do 3.3 V.
2. **Převod ADC**: ESP32 převádí analogové napětí na digitální číslo v rozsahu **0 až 4095** (12-bitové rozlišení ADC).
3. **Výpočet napětí a grafika**: Program v C++ přepočítává naměřené číslo na přesné napětí v Voltech (`voltage = rawValue * (3.3 / 4095.0)`) a v Sériovém monitoru zobrazuje textový progress bar `[==========          ]`.

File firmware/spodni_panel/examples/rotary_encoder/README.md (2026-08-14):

# Příklad: Rotační Enkodér (KY-040)

Tento příklad demonstruje přesné čtení inkrementálního rotačního enkodéru (např. modul **KY-040**) s integrovaným tlačítkem. Kód využívá **hardwarové přerušení (ISR)** a softwarový filtr zákmitů (debouncing).

---

## Hardwarové zapojení

| Pin na Enkodéru | Funkce | ESP32 DevKit Pin | Poznámka |
| :--- | :--- | :--- | :--- |
| **GND** | Zem | **GND** | Společná zem |
| **+ / VCC** | Napájení | **3.3V** | Napájení 3.3V |
| **CLK / A** | Hodinový signál | **GPIO 32** | Vstup s interním PULL-UPem |
| **DT / B** | Datový signál | **GPIO 4** | Vstup s interním PULL-UPem |
| **SW** | Tlačítko | **GPIO 18** | Vstup s interním PULL-UPem (spíná proti GND) |

---

## Jak to funguje
1. **Kvadraturní enkodér**: Otáčením hřídelky generuje enkodér dva fázově posunuté obdélníkové signály (CLK a DT). Podle toho, který signál změní stav dříve, mikrokontrolér pozná směr otáčení (CW = po směru, CCW = proti směru).
2. **Hardwarové přerušení (`attachInterrupt`)**: Při každé klesající hraně na pinu `CLK` se okamžitě vyvolá obslužná funkce `handleEncoderISR()`, což zaručuje, že nepřehlédneme žádný krok ani při velmi rychlém otáčení.
3. **Debouncing (odrušení zámitů)**: V přerušení se pomocí `micros()` kontroluje minimální časový odstup (2 ms) mezi pulzy, čímž se eliminují mechanické zákmity kontaktů.
4. **Reset tlačítkem**: Stisk hřídelky (tlačítko SW) vyvolá přerušení `handleButtonISR()`, které vynuluje počítadlo polohy zpět na `0`.

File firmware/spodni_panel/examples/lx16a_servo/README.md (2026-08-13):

# Příklad: Chytré servo LX-16A (Sériová sběrnice)

Tento příklad demonstruje komunikaci s chytrým sériovým servomotorem **Lewansoul LX-16A** připojeným ke spodnímu panelu s ESP32. Kód nejprve zjistí aktuální ID serva (předpokládá se ID 1) a následně jej změní na vyžadované **ID 0**.

## Hardwarové zapojení

Sériová serva typu LX-16A komunikují po jednovodičové sběrnici (Half-Duplex Serial). Knihovna automaticky konfiguruje UART rozhraní ESP32 do jednovodičového režimu na vybraném pinu.

| LX-16A Konektor (Pin) | ESP32 DevKit Pin | Popis |
| --- | --- | ----- |
| **G** / **GND** (Zem)  | **GND** | Společná zem |
| **V** / **VCC** (Napájení)| **Vnější zdroj** (6V - 7.4V) | Napájení serva (nepřipojovat přímo na 3.3V pin ESP32!) |
| **D** / **RX/TX** (Data)| **GPIO 14** | Jednovodičová datová sběrnice |

Pevné zapojení

*Upozornění: Serva LX-16A vyžadují napájecí napětí v rozsahu **6.0V až 7.4V** (ideálně 2S LiPo baterie nebo stabilizovaný síťový zdroj). Napájení přímo z USB přes ESP32 (5V) může fungovat pro čtení registrů/ID a pro pohyb naprázdno, ale při zátěži dojde k resetu ESP32 z důvodu proudového přetížení.*

*Doporučení pro spolehlivý provoz: Přestože zapojení funguje napřímo (díky tomu, že ESP32 podporuje jednovodičový Half-Duplex režim a servo detekuje 3.3V úrovně), pro dlouhodobý a bezpečný provoz se doporučuje mezi ESP32 a servo zapojit **převodník logických úrovní (Logic Level Shifter)** z 3.3V na 5V. Tím se ochrání GPIO pin ESP32 před 5V úrovněmi ze serva a výrazně se zvýší stabilita komunikace při delších vodičích.*

---

## Použité knihovny
- **Esp32-lx16a** (https://github.com/RoboticsBrno/Esp32-lx16a)

Knihovna se do projektu instaluje přímo z GitHub repozitáře, nastavení je uvedeno v `platformio.ini`.

## Jak to funguje
1. Sběrnice serva se inicializuje v `setup()` pomocí `servoBus.begin(1, UART_NUM_2, GPIO_NUM_14)`. Parametry znamenají:
   - Počet serv: 1
   - Hardwarový UART: UART2
   - Datový pin: GPIO 14
2. Kód vyšle broadcast dotaz na ID `254` (adresa, na kterou odpoví jakékoliv jediné připojené servo).
3. Pokud servo odpoví, kód zkontroluje jeho aktuální ID.
4. Pokud je ID různé od `0` (např. tovární ID 1), kód pošle příkaz ke změně ID na `0` a změnu následně zpětně ověří.
5. V loopu program periodicky ověřuje přítomnost serva s ID 0 každých 5 sekund a vypisuje stav na sériový monitor (rychlost **115200 baudů**).

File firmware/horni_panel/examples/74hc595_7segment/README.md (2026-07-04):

# Příklad: Sedmisegmentový displej s posuvnými registry 74HC595 (Static Drive)

Tento příklad demonstruje připojení a ovládání vícemístného sedmisegmentového LED displeje řízeného kaskádou posuvných registrů **74HC595** k mikrokontroléru **ESP32-S3**.

Program používá softwarové SPI (bit-banging) na libovolných GPIO pinech bez potřeby externích knihoven a každých 500 ms inkrementuje běžící počítadlo.

---

## Propojení (Zapojení)

Displej je připojen pomocí 3 datových linek:

| Pin Displeje | ESP32-S3 Pin | Popis |
| --- | --- | ----- |
| **VCC** | `5V` (nebo `3V3`*) | Napájení (pro jasnější LED doporučujeme 5V větev) |
| **GND** | `GND` | Společná zem |
| **DIO / DS (Data)** | `GPIO 7` | Vstup sériových dat (Data Input / Serial Data) |
| **SCLK / SH_CP (Clock)** | `GPIO 3` | Hodiny posuvu (Shift Register Clock) |
| **RCLK / ST_CP (Latch)** | `GPIO 4` | Latch / Zkopírování dat na výstupy (Storage Register Clock) |

*\* Poznámka k napájení: Většina 74HC595 modulů s LED displeji funguje i na 3.3 V z ESP32-S3, ale pro vyšší jas doporučujeme 5 V.*

---

## Princip fungování posuvného registru 74HC595 (Maturitní obhajoba)

Při obhajobě maturitního projektu můžeš vysvětlit následující technické principy:

1. **Sériově-Paralelní převodník (SISO/SIPO)**:
   * 74HC595 je 8-bitový posuvný registr se záchytným registrem (latch).
   * Přijímá data sériově po jednom bitu (přes pin **DS / DIO**) a na povel hodinového signálu (**SH_CP / SCLK**) posune data o jednu pozici dál.
   * Jakmile odešleme všech 8 bitů (celý bajt), vyšleme pulz na pin **ST_CP / RCLK (Latch)**, který zkopíruje stav z posuvného registru na 8 výstupních pinů (Q0–Q7) naráz. Tím se zabrání "blikání" segmentů během posouvání dat.
2. **Kaskádové zapojení (Daisy Chaining)**:
   * Posuvný registr má výstupní pin **Q7'** (Serial Out). Když do čipu pošleme 9. bit, 1. bit "přeteče" ven přes tento pin.
   * Propojením pinu Q7' prvního čipu na pin DS druhého čipu zapojíme registry do kaskády. To nám umožňuje ovládat např. 3 číslice (3 čipy = 24 výstupů) pomocí stále stejných 3 vodičů z ESP32-S3.
3. **Statické buzení (Static Drive)**:
   * Na rozdíl od dynamického buzení (multiplexování), kde procesor musí neustále střídat rozsvěcování jednotlivých číslic, u statického buzení drží výstupy 74HC595 stálé napětí.
   * Procesor pošle data pouze tehdy, když se hodnota mění. Displej nebliká a nezatěžuje procesor.

---

## Binární kód, Desetinná tečka a Hexadecimální převod

Pro ovládání segmentů číslic posíláme do registru **jeden bajt (8 bitů)** pro každou číslici.

### Schéma segmentů displeje
Každá číslice se skládá z následujících segmentů označených písmeny **A** až **G** a desetinné tečky **DP**:
```text
      --- A ---
     |         |
     F         B
     |         |
      --- G ---
     |         |
     E         C
     |         |
      --- D ---   [DP] (tečka)
```

### Mapování bitů v bajtu
Každý bit v odesílaném bajtu ovládá konkrétní segment na displeji:

| Bit pozice | Bit 7 | Bit 6 | Bit 5 | Bit 4 | Bit 3 | Bit 2 | Bit 1 | Bit 0 |
| :--- | :---: | :---: | :---: | :---: | :---: | :---: | :---: | :---: |
| **Segment** | **DP** (tečka) | **G** | **F** | **E** | **D** | **C** | **B** | **A** |

*   **Bit 0 (LSB - nejnižší bit):** Ovládá segment **A** (horní vodorovná čárka).
*   **Bit 7 (MSB - nejvyšší bit):** Ovládá desetinnou tečku **DP**.

### Co znamená prefix `0b` a `0x`?
V programování se používají předpony (prefixy) pro rozlišení číselných soustav:
*   **`0b` (Binary)** – Značí dvojkovou (binární) soustavu. Např. `0b01111111` je zápis osmi konkrétních jedniček a nul.
*   **`0x` (Hexadecimal)** – Značí šestnáctkovou soustavu. Např. `0x7F` je zkrácený zápis pro stejnou hodnotu.

### Jak převést binární kód (`0b`) na šestnáctkový (`0x`)?
Převod provedeme tak, že 8bitový bajt rozdělíme napůl na dvě čtveřice bitů (nibbly) a každou čtveřici převedeme na jeden šestnáctkový znak (0-9, A-F):

1.  **Číslo 8 bez tečky** (`0b01111111`):
    *   Levá polovina: `0111` $\rightarrow$ V desítkové soustavě 7 $\rightarrow$ Hexadecimálně **`7`**
    *   Pravá polovina: `1111` $\rightarrow$ V desítkové soustavě 15 $\rightarrow$ Hexadecimálně **`F`**
    *   Dohromady: **`0x7F`**
2.  **Číslo 8 s tečkou** (`0b11111111`):
    *   Levá polovina: `1111` $\rightarrow$ V desítkové soustavě 15 $\rightarrow$ Hexadecimálně **`F`**
    *   Pravá polovina: `1111` $\rightarrow$ V desítkové soustavě 15 $\rightarrow$ Hexadecimálně **`F`**
    *   Dohromady: **`0xFF`**

### Rozdíl mezi 8 a 8 s tečkou:
Rozdíl je pouze v nejvyšším bitu (Bit 7 / DP), který leží úplně vlevo:
*   **8 bez tečky:** `0b01111111` (nejvyšší bit = `0` $\rightarrow$ tečka nesvítí) $\rightarrow$ **`0x7F`**
*   **8 s tečkou:** `0b11111111` (nejvyšší bit = `1` $\rightarrow$ tečka svítí) $\rightarrow$ **`0xFF`**

*(Poznámka: U displeje se Společnou Anodou se tato logika invertuje, takže u 8 s tečkou svítí všechny segmenty při přivedení nul, tzn. binárně `0b00000000` / `0x00`).*

---

## Nastavení typu displeje v kódu

Většina levných čínských modulů s 74HC595 používá LED displeje se **Společnou Anodou (Common Anode)**. Pro rozsvícení segmentu je potřeba přivést logickou nulu (`0`).
Některé moduly ale mohou mít **Společnou Katodu (Common Cathode)**, kde se segmenty rozsvěcují logickou jedničkou (`1`).

V kódu toto chování snadno přepneš změnou konstanty:
```cpp
const bool COMMON_ANODE = true; // Nastav na false, pokud segmenty svítí opačně.
```

---

## Jak spustit tento příklad

1. Propojte displej podle tabulky zapojení (přepojte CS na GPIO 4).
2. Zkopírujte kód ze souboru `main.cpp` v této složce a nahraďte jím kód v `src/main.cpp`.
3. Nahrajte program do ESP32-S3.
4. Počítadlo začne běžet od nuly a každých 500 ms se zvýší o 1.

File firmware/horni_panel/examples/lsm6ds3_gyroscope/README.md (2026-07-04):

# Příklad: Inerciální senzor LSM6DS3 (Gyroskop, Akcelerometr & Pokročilé Funkce)

Tento příklad demonstruje kompletní vyčítání a zpracování dat ze 6-osého inerciálního senzoru (IMU) **LSM6DS3** připojeného k **ESP32-S3** přes hardwarovou sběrnici I2C0.

Složka obsahuje jak hlavní stabilní program s **komplementárním filtrem**, tak samostatné ukázky demonstrující **pokročilé hardwarové koprocesory** senzoru LSM6DS3 (krokoměr, detekce poklepání, volný pád a 6D orientace v prostoru).

---

## 1. Hlavní program: Komplementární filtr (`main.cpp`)

V hlavní ukázce (`main.cpp`) je implementován **komplementární filtr** (Complementary Filter), který kombinuje data z gyroskopu a akcelerometru a řeší tak zásadní fyzikální nedostatek inerciálních systémů – **integrační drift gyroskopu**.

### Jak komplementární filtr funguje:
1. **Gyroskop** měří úhlovou rychlost. Je velmi rychlý a přesný v krátkém čase, ale v čase driftuje (chyba se neustále kumuluje integrací $\theta = \int \omega \, dt$).
2. **Akcelerometr** měří gravitační zrychlení. Dlouhodobě ukazuje, kde je stabilní směr dolů k zemi, ale krátkodobě je velmi náchylný na jakékoliv otřesy.
3. **Filtr** tyto informace spojuje do rovnice (s váhou $\alpha = 0.98$):
   $$\theta_{nový} = \alpha \cdot (\theta_{starý} + \omega_{gyro} \cdot dt) + (1 - \alpha) \cdot \theta_{accel}$$
   * **Roll (osa X)** a **Pitch (osa Y)** jsou díky tomu naprosto stabilní, nedriftují a při navrácení do původní polohy ukazují přesně $0^\circ$.
   * **Yaw (osa Z)** je rovnoběžný s gravitačním vektorem, proto jej nelze akcelerometrem korigovat a využívá čistou numerickou integraci gyroskopu.

---

## 2. Pokročilé příklady (Advanced Hardware Examples)

Tyto přiložené soubory demonstrují výpočty probíhající přímo v hardwarovém koprocesoru senzoru LSM6DS3:

*   **`pedometer.cpp` (Krokoměr)**:
    *   Ukazuje spuštění integrovaného krokoměru a čtení počtu kroků z registru `readPedometer()` bez softwarového filtrování v ESP32.
*   **`tap_detection.cpp` (Detekce poklepání)**:
    *   Provádí přímou konfiguraci I2C registrů (`TAP_CFG`, `TAP_THS_6D`, `INT_DUR2`, `WAKEUP_THS`) pro detekci **jednoduchého a dvojitého poklepání** (Single & Double Tap) na senzor v libovolné ose.
*   **`free_fall.cpp` (Detekce volného pádu)**:
    *   Nastavuje registry pro detekci stavu bez tíže (když celkové zrychlení klesne pod definovaný práh po stanovenou dobu) a vyvolá poplach.
*   **`orientation_6d.cpp` (6D Orientace v prostoru)**:
    *   Sleduje naklonění senzoru vůči gravitaci a detekuje 6 poloh: lícem nahoru, lícem dolů, levý/pravý bok, otočení na výšku (Portrait / Landscape).

---

## Propojení (Zapojení)

Senzor LSM6DS3 je připojen na I2C0 sběrnici ESP32-S3:

| LSM6DS3 Pin | ESP32-S3 Pin | Popis |
| --- | --- | ----- |
| **VCC / VIN** | `3V3` | Napájení senzoru (3.3 V) |
| **GND** | `GND` | Společná zem |
| **SDA** | `GPIO 8` | I2C Datová linka (SDA) |
| **SCL** | `GPIO 9` | I2C Hodinová linka (SCL) |

---

## Jak spustit příklady

1. Propojte senzor LSM6DS3 podle tabulky.
2. Zkopírujte kód vybraného příkladu (např. `main.cpp` nebo `tap_detection.cpp`) a nahraďte jím obsah hlavního souboru `src/main.cpp` v projektu.
3. Sestavte a nahrajte projekt do desky (**Build & Upload**).
4. Otevřete sériový monitor na rychlosti **115200 baudů**.

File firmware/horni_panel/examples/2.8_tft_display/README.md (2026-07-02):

# Grafické příklady: 2.8" TFT LCD displej (ILI9341 / ST7789)

Tato složka obsahuje ukázkové příklady pro rozběhnutí a testování **2.8" TFT LCD displeje** (rozlišení 240×320, řadič ILI9341 kompatibilní se ST7789) zapojeného přes hardwarové SPI na mikrokontroléru **ESP32-S3 DevKitC-1**.

---

## Propojení (Zapojení pinů)

Displej je pevně připojen k ESP32-S3 pomocí následujícího hardwarového mapování:

| Displej Pin | ESP32-S3 GPIO | Popis |
| --- | --- | ----- |
| **VCC** | `5V` (VEXT) | Napájení displeje |
| **GND** | `GND` | Společná zem |
| **CS** | `GPIO 10` | Chip Select (výběr SPI čipu) |
| **RESET** | `GPIO 14` | Reset displeje |
| **DC** | `GPIO 13` | Data/Command (výběr dat/příkazu) |
| **SDI (MOSI)**| `GPIO 11` | Hardware SPI Master Out Slave In |
| **SCK** | `GPIO 12` | Hardware SPI Clock (hodinový signál) |
| **LED** | `3.3V` | Podsvícení displeje (napojeno trvale) |
| **SDO (MISO)**| *Nezapojeno* | Master In Slave Out (dotyková vrstva se neřeší) |

---

## Přehled příkladů v této složce

Ve složce naleznete tyto ukázkové zdrojové kódy:

1. **[main.cpp](main.cpp)**:
   * **Základní test displeje**: Vykreslí statický barevný testovací obrazec, zarovnané textové popisky a ohraničující linky. Ideální pro první ověření správného zapojení pinů a komunikace.
2. **[dashboard.cpp](dashboard.cpp)**:
   * **Prémiový systémový panel**: Zobrazuje simulované metriky systému (Uptime, volná paměť RAM, teplota CPU), animovaný progress bar, blikající stavovou LED diodu a především **živý, plynulý osciloskop** kreslící neonově zelenou vlnovou křivku bez blikání displeje.
3. **[3d_engine.cpp](3d_engine.cpp)**:
   * **3D Projekční engine**: Matematicky počítá a perspektivně promítá **dvě drátěné kostky** rotující v opačných směrech ve všech 3 osách. Na pozadí se pohybuje 3D hvězdné pole s jasem závislým na hloubce hvězdy. Celé zobrazení je doplněno futuristickým HUD rámem s reálným čítačem FPS (~20 FPS) a úhlů rotace.
4. **[multi_view.cpp](multi_view.cpp)**:
   * **Multi-View manažer (3 obrazovky)**: Spojuje Dashboard, 3D Engine a **retro hru Had (Snake autoplay)** do jednoho běžícího celku. Každých 5 sekund provede **laserový přechodový efekt** (tyrkysový paprsek zamete obrazovku) a přepne zobrazení na další v pořadí.
   * *Autoplay Had*: Had se sám naviguje za jablkem, zvětšuje se, připočítává skóre a při zablokování se automaticky resetuje.

---

## Jak spustit jakýkoliv příklad

1. Propojte displej s ESP32-S3 přesně podle tabulky zapojení výše.
2. Vyberte si ukázkový soubor (např. `multi_view.cpp`).
3. Zkopírujte celý jeho obsah.
4. Otevřete hlavní soubor projektu **[src/main.cpp](../../src/main.cpp)** a přepište jej zkopírovaným obsahem.
5. V PlatformIO spusťte nahrávání (**Build and Upload**).

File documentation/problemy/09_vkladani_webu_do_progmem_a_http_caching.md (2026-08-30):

# Problém: Vkládání webového rozhraní do Flash paměti (`PROGMEM`), HTTP Caching a trvalá paměť

## Popis problému

Při tvorbě asynchronního webového serveru a WebSocket rozhraní pro **ESP-Demo-Box** vznikla potřeba vytvořit moderní a responzivní HTML5/CSS3/JS dashboard pro mobilní telefony. Objevily se následující zásadní otázky týkající se architektury paměti a přenosu dat:

1. **Vztah webových souborů a C++ kódu:** Jak přesně souvisí standardní webové soubory (`index.html`, `style.css`, `script.js`) s C++ hlavičkovým souborem `WebPages.h`? Jak se kód webu dostane do mikrokontroléru?
2. **Správa paměti v ESP32 (`PROGMEM`):** Jak funguje ukládání webových stránek v paměti mikrokontroléru, aby nedošlo k vyčerpání vzácné operační paměti RAM?
3. **Průběh síťového přenosu:** Jak přesně probíhá vyžádání a posílání webových souborů z ESP32 do mobilního telefonu po připojení na Wi-Fi?
4. **Klientská mezipaměť (HTTP Caching):** Jak zařídit, aby telefon nemusel při každém otevření stahovat velký CSS a JS soubor znovu z ESP32?
5. **Trvalé ukládání naměřených dat (Non-Volatile Storage):** Lze do Flash paměti ESP32 ukládat naměřené hodnoty (např. historii teploty), aby zůstaly zachovány i po vypnutí napájení?

---

## Rozbor a Řešení

### 1. Vztah webových souborů a `WebPages.h`

Kompilátor C++ (GCC) pro ESP32 neumí přímo kompilovat samostatné `.html`, `.css` nebo `.js` soubory jako kód. Zná pouze C++ datové typy (řetězce `const char[]`).

* **Soubory `index.html`, `style.css`, `script.js`:** Slouží jako zdrojové soubory pro pohodlnou vývojářskou práci ve VS Code (se syntaktickým zvýrazňováním a kontrolou syntaxe).
* **Soubor `WebPages.h`:** Obsahuje **přesné kopie textu** těchto souborů vložené do C++ konstanta řetězců pomocí C++ *Raw String Literal* (`R"rawliteral(...)rawliteral"`):

```cpp
// Ukázka z WebPages.h: HTML kód je vložen do C++ řetězce INDEX_HTML
const char INDEX_HTML[] PROGMEM = R"rawliteral(
<!DOCTYPE html>
<html lang="cs">
<head>
    <link rel="stylesheet" href="style.css">
</head>
<body> ... </body>
</html>
)rawliteral";
```

Díky zápisu `R"rawliteral(...)"` si C++ nevšímá uvozovek ani nových řádků uvnitř HTML/CSS/JS a bere celý blok jako jeden čistý řetězec znaků.

---

### 2. Ukládání v paměti mikrokontroléru (`PROGMEM` / Flash vs. RAM)

ESP32-S3 disponuje dvěma typy paměti:
* **RAM (Internal SRAM - cca 512 KB):** Rychlá operační paměť pro proměnné, výpočty a zásobník úloh FreeRTOS.
* **Flash (External SPI Flash - 16 MB):** Trvalé uložení nahraného programu (firmware).

Kdybychom proměnné webu definovali bez makra `PROGMEM`, kompilátor by je při startu ESP32 zkopíroval z Flash do RAM paměti, což by spotřebovalo zbytečně desítky kilobajtů RAM.

Klíčové slovo **`PROGMEM`** (Program Memory) instruuje kompilátor:
> *"Tato data ponechej trvale uložená ve Flash paměti. Nenačítej je při startu do RAM. Až je bude síťový server potřebovat poslata mobilu, přečti je přímo z Flash."*

---

### 3. Průběh síťového přenosu z ESP32 do telefonu

Když se mobil připojí k Wi-Fi `ESP-Demo-Box` a otevře rozhraní, proběhne následující sekvence požadavků:

1. **Požadavek 1 (HTML):** Mobil pošle `GET / HTTP/1.1`.
   * ESP32 v `WebManager.cpp` zavolá:  
     `request->beginResponse_P(200, "text/html", INDEX_HTML);`
   * Přečte `INDEX_HTML` z Flash paměti a odešle ho do mobilu.
2. **Parsing v mobilu:** Prohlížeč v mobilu přečte HTML a narazí na tagy `<link rel="stylesheet" href="style.css">` a `<script src="script.js"></script>`.
3. **Požadavek 2 (CSS):** Mobil pošle `GET /style.css HTTP/1.1`.
   * ESP32 odpoví zprávou obsahující `STYLE_CSS` z Flash.
4. **Požadavek 3 (JS):** Mobil pošle `GET /script.js HTTP/1.1`.
   * ESP32 odpoví zprávou obsahující `SCRIPT_JS` z Flash.
5. **Navázání WebSocketu:** `script.js` v mobilu spustí `new WebSocket("ws://192.168.4.1/ws")`. Od této chvíle se již HTTP soubory nestahují a obě strany si posílají pouze malé živé JSON balíčky o velikosti ~200 B.

---

### 4. Klientská mezipaměť (HTTP Caching)

Aby mobil nemusel při každém novém otevření webu stahovat CSS a JS soubory z ESP32 znovu, přibaluje ESP32 k HTTP odpovědi hlavičku **`Cache-Control`**:

```cpp
response->addHeader("Cache-Control", "public, max-age=86400"); // 86400 sekund = 24 hodin
```

* **Efekt:** Prohlížeč v mobilním telefonu si soubory `style.css` a `script.js` uloží do své lokální paměti.
* Při dalším načtení stránky mobil z ESP32 stáhne pouze lehoučké HTML a styly i skripty vytáhne ze své vlastní paměti. Tím se šetří přenosové pásmo Wi-Fi a CPU výkon ESP32.

---

### 5. Trvalé ukládání naměřených dat ve Flash paměti (NVS & LittleFS)

**Ano! Do Flash paměti ESP32 lze ukládat libovolná naměřená data (např. historii teplot, logy chyby, kalibraci), která zůstanou zachována i po kompletním vypnutí napájení.**

V prostředí ESP32/Arduino se pro trvalé ukládání používají 2 hlavním způsoby:

#### A) Knihovna `Preferences` (NVS - Non-Volatile Storage)
* Vhodné pro drobné hodnoty (nastavení, uložené módy, kalibrace, počítadla).
* Ukládá data jako dvojice *Klíč -> Hodnota*.
```cpp
#include <Preferences.h>
Preferences prefs;

// Zápis uložené teploty
prefs.begin("sensors", false); // Otevřít sekci "sensors" pro zápis
prefs.putFloat("lastTemp", 24.5);
prefs.end();

// Čtení po restartu/zapnutí
prefs.begin("sensors", true);  // Otevřít pouze pro čtení
float temp = prefs.getFloat("lastTemp", 0.0);
prefs.end();
```

#### B) Souborový systém `LittleFS`
* Vhodné pro věší množství strukturovaných dat (např. soubor `history.csv` s tisíci naměřenými teplotami).
```cpp
#include <LittleFS.h>

// Uložení jednoho řádku měření do souboru
File file = LittleFS.open("/history.csv", FILE_APPEND);
if (file) {
    file.printf("%lu,%.2f,%.2f\n", millis(), temp, hum);
    file.close();
}
```

> [!NOTE]
> **Pozor na opotřebení Flash paměti (Wear Leveling):** Flash paměť má omezený počet zápisových cyklů (cca 100 000 zápisů na sektor). Proto se naměřená data neukládají do Flash každou sekundu, ale ukládají se v bufferu v RAM a do Flash se zapisují např. jen jednou za hodinu nebo při vypínání systému.

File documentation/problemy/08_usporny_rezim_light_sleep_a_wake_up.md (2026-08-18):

# 08. Úsporný režim Light Sleep a asynchronní probouzení (Wake-up Zdroje)

## 1. Úvod a formulace problému
Při vývoji bateriově nebo dlouhodobě napájených vestavěných systémů (Embedded Systems), jako je náš **ESP-Demo-Box**, je klíčovým parametrem celková energetická bilance zařízení. Mikrokontrolér ESP32-S3 při plném taktu dvou jader na frekvenci **240 MHz** a se zapnutým Wi-Fi/Bluetooth vysílačem odebírá proud v rozmezí **100 mA až 250 mA**. V klidovém stavu (kdy uživatel s demo boxem neinteraguje) by takový trvalý odběr vedl k rychlému vybití bateriového článku nebo zbytečnému zahřívání komponent uvnitř uzavřeného kufru.

Cílem bylo implementovat inteligentní režim spánku (**Sleep Mode**), který po dokončení demo prezentace uvede systém do klidového stavu s minimálním odběrem proudu, ale zároveň umožní **okamžité a plynulé probuzení** bez nutnosti provádět kompletní studený restart systému (Cold Boot).

Během implementace a testování jsme však narazili na závažné systémové komplikace:
1. **Hardwarový konflikt s Octal SPI Flash/PSRAM sběrnicí:** Volba nesprávného GPIO pinu pro přerušení vedla k okamžitému pádu řadiče cache paměti a pádu procesoru.
2. **Kolize úloh a zacyklení Watchdogu (TG1WDT):** Nesprávné zacházení se stavy přerušení a zamykáním I2C sběrnice v reálném čase shazovalo FreeRTOS.
3. **Zacyklení stavového automatu:** Návrat z režimu spánku do předchozího módu způsoboval okamžitý opakovaný přechod do spánku.

---

## 2. Proč to děláme a volba režimu spánku (Light Sleep vs. Deep Sleep)

V architektuře mikrokontrolérů ESP32 rozlišujeme několik úrovní spánku:

| Parametr | Aktivní režim | Light Sleep (Náš výběr) | Deep Sleep |
| :--- | :--- | :--- | :--- |
| **Takt CPU** | 240 MHz (Aktivní) | **Zastaven (Gated)** | Zcela vypnut |
| **Spotřeba proudu** | 100–240 mA | **cca 0.8–2 mA** | cca 10–50 µA |
| **Obsah RAM paměti** | Zachován | **100% Zachován** | Ztracen (zůstává jen RTC RAM) |
| **Běh FreeRTOS úloh** | Běží v reálném čase | **Zmrazeny na místě** | Ukončeny |
| **Čas probuzení** | Okamžitý (0 ms) | **< 1 ms (Okamžité pokračování)** | 100–500 ms (Restart programu) |

### Proč jsme zvolili Light Sleep?
Pro interaktivní prezentační kufřík je **Deep Sleep nevhodný**, protože po probuzení vyžaduje kompletní restart programu (`setup()`), znovu inicializuje displej, sběrnice I2C/SPI a ztrácí rozpracovaný stav her (např. rozehranou hru Had, 2048 či pozice menu).

**Light Sleep** naproti tomu zmrazí hodinový signál procesoru (Clock Gating), čímž srazí spotřebu o více než **98 %**, ale paměť RAM a všechny FreeRTOS tasky zůstávají nedotčeny. V momentě příchodu vnějšího impulsu procesor pokračuje přesně na dalším řádku kódu za `esp_light_sleep_start()`.

---

## 3. Asynchronní zdroje probuzení (Tri-Source Wake-up Architecture)

Systém horního panelu byl navržen tak, aby reagoval na tři nezávislé podněty z vnějšího prostředí:

```mermaid
graph TD
    A["ESP32-S3 (Light Sleep)<br>Spotřeba &lt; 2 mA"] -->|Událost| W["Okamžité probuzení (&lt; 1 ms)"]
    
    T1["1. Horní Tlačítko 1<br>(GPIO 47, LOW level)"] -->|Stisk uživatele| A
    T2["2. Akcelerometr LSM6DS3<br>(GPIO 45 INT1, HIGH level)"] -->|Klepnutí / Otřes kufru| A
    T3["3. Dolní panel přes UART<br>(UART1 RX, Data ready)"] -->|Pohyb joysticku / Tlačítko zdola| A
    
    W --> D["Diagnostika esp_sleep_get_wakeup_cause()"]
    D --> S["Obnova stavu: SystemState::setMode()"]
```

### 1. Horní tlačítko 1 (`PIN_BTN1` – GPIO 47)
* **Princip:** Hardwarový pin je konfigurován s vnitřním pull-up rezistorem (`INPUT_PULLUP`).
* **Spouštěcí podmínka:** Logická nula (`GPIO_INTR_LOW_LEVEL`) při stisku tlačítka proti zemi (GND).

### 2. Otřes a klepnutí na kufr přes IMU (`PIN_IMU_INT` – GPIO 45)
* **Princip:** Senzor LSM6DS3 má v sobě vestavěný hardwarový komparátor zrychlení s horní propustí (High-Pass / Slope Filter), který automaticky odečítá zemskou gravitaci $1\text{ g}$.
* **Nastavení registrů:**
  * `TAP_CFG (0x58) = 0x90`: Povolení interních přerušení a zapnutí slope filtru.
  * `WAKE_UP_DUR (0x5C) = 0x00`: Okamžitá reakce na ráz.
  * `WAKE_UP_THS (0x5B) = 0x01`: Maximální citlivost prahu (cca $31.25\text{ mg}$ nad gravitaci).
  * `MD1_CFG (0x5E) = 0x20`: Přesměrování signálu Wake-Up na fyzický výstupní pin `INT1`.
* **Spouštěcí podmínka:** Logická jednička (`GPIO_INTR_HIGH_LEVEL`), kdy pin `INT1` vystřelí 3.3 V impuls.

### 3. Vnější komunikace z Dolního panelu (`UART1`)
* **Princip:** ESP32-S3 hardwarový UART řadič dokáže detekovat sestupné hrany na přijímacím pinu `RX`.
* **Spouštěcí podmínka:** `esp_sleep_enable_uart_wakeup(1)` – jakmile uživatel na spodním panelu pohne joystickem nebo stiskne tlačítko, dolní ESP odešle datový rámec, jehož první start bajt okamžitě probudí horní procesor ze spánku.

---

## 4. Technické problémy při vývoji a jejich řešení

### Problém A: Kolize s interní sběrnicí Octal SPI Flash/PSRAM (Pád `TG1WDT_SYS_RST`)
Při počátečním návrhu byl přerušovací pin `PIN_IMU_INT` omylem přiřazen na **GPIO 36**.
* **Důvod havárie:** Deska `ESP32-S3-DevKitC-1` s 16 MB Flash a 8 MB Octal PSRAM využívá režim `opi_opi`. V tomto režimu jsou piny **GPIO 33 až 37 vyhrazeny interní vysokorychlostní sběrnici Flash a PSRAM** (linka `SPI_IO6`).
* V momentě, kdy software zavolal `pinMode(36, INPUT_PULLDOWN)` nebo `gpio_wakeup_enable(36, ...)`, fyzicky odpojil paměťový čip od řadiče cache. Procesor ztratil schopnost načítat instrukce z paměti Flash, sběrnice zamrzla a hardwarový hlídací pes Timer Group 1 (`TG1WDT`) desku v nekonečné smyčce resetoval.
* **Řešení:** Přemapování signálu `PIN_IMU_INT` na plně nezávislý a bezpečný pin **`GPIO 45`**, který nemá žádné sdílené funkce s pamětí.

### Problém B: Falešné probouzení kvůli Data-Ready (DRDY) šumu
Při prvotním použití knihovny Adafruit LSM6DS byla aktivována funkce `configInt1(false, false, true)`, která na pin `INT1` posílala signál Data-Ready s frekvencí 100 Hz. Pin byl prakticky neustále v úrovni HIGH, takže mikrokontrolér po zavolání `esp_light_sleep_start()` okamžitě (za 0.001 ms) vyskočil ze spánku.
* **Řešení:** Vypnutí DRDY pomocí `lsm6ds3.configInt1(false, false, false)` a konfigurace čistého hardwarového přerušení otřesu přes I2C registry `TAP_CFG` a `WAKE_UP_THS`.

### Problém C: Zacyklení stavového automatu po probuzení
Když systém usnul po dokončení módu 10 (Barevný mód), obnovení předchozího stavu pomocí `globalState.getLastMode()` vrátilo hodnotu 10. Simulátor demo režimu následně vyhodnotil čas a v téže vteřině poslal systém znovu do spánku.
* **Řešení:** V `SystemState::setMode()` byla přidána podmínka zamezující uložení `MODE_SLEEP` do `lastMode`. V `main.cpp` bylo ošetřeno, že pokud byl předchozí mód zakončením demo cyklu, systém se probudí do výchozího `MODE_MAIN_MENU`.

---

## 5. Implementovaný zdrojový kód (Ukázka z `main.cpp`)

```cpp
// =======================================================
// STAVOVÝ AUTOMAT: REŽIM SPÁNKU A PROBUZENÍ
// =======================================================
case MODE_SLEEP: {
    Serial.println("[SYSTEM] Prechazim do rezimu Light Sleep...");

    // 1. Zhasnutí výstupů a grafiky
    gfx.clearScreen(ST77XX_BLACK);

    // 2. Vyprázdnění sériových linek před zmrazením hodin
    Serial.flush();
    #ifdef ENABLE_UART_ESP
        SerialESP.flush();
    #endif

    // 3. Nastavení asynchronních zdrojů probuzení
    #ifdef PIN_BTN1
        // A) Stisk horního tlačítka 1 (aktivní LOW)
        gpio_wakeup_enable((gpio_num_t)PIN_BTN1, GPIO_INTR_LOW_LEVEL);
    #endif

    #ifdef PIN_IMU_INT
        // B) Detekce otřesu / klepnutí z LSM6DS3 (aktivní HIGH na GPIO 45)
        gpio_wakeup_enable((gpio_num_t)PIN_IMU_INT, GPIO_INTR_HIGH_LEVEL);
    #endif

    esp_sleep_enable_gpio_wakeup();

    #ifdef ENABLE_UART_ESP
        // C) Příchod dat z dolního mikrokontroléru přes UART1
        esp_sleep_enable_uart_wakeup(1);
    #endif

    // 4. VSTUP DO LIGHT SLEEP (Procesor zmrazí takt, RAM zachována)
    esp_light_sleep_start();

    // ===================================================
    // 5. OKAMŽITÉ PROBUZENÍ (Latence < 1 ms)
    // ===================================================
    esp_sleep_wakeup_cause_t duvod = esp_sleep_get_wakeup_cause();
    Serial.printf("[SYSTEM] Probudil jsem se! (Kod: %d) -> ", (int)duvod);
    
    if (duvod == ESP_SLEEP_WAKEUP_GPIO) {
        Serial.println("PROBUZENO TLACITKEM NEBO OTRESEM (GPIO)");
    } else if (duvod == ESP_SLEEP_WAKEUP_UART) {
        Serial.println("PROBUZENO Z DOLNIHO PANELU (UART)");
    }

    // Krátká prodleva pro stabilizaci sběrnic a úloh
    vTaskDelay(pdMS_TO_TICKS(100));

    // Inteligentní návrat do stavu před spánkem
    AppMode returnMode = globalState.getLastMode();
    if (returnMode == MODE_SLEEP || returnMode == MODE_BAREVNY) {
        returnMode = MODE_MAIN_MENU;
    }
    globalState.setMode(returnMode);
    break;
}
```

---

## 6. Přínos pro maturitní práci
* **Demonstrace pokročilého power managementu:** Projekt ukazuje schopnost optimalizovat energetickou náročnost vestavěných systémů na úrovni mikroampérů a miliampérů.
* **Architektonická robustnost:** Kombinace tří různých hardwarových periferií (GPIO, I2C IMU, UART) pro asynchronní probuzení procesoru.
* **Detailní znalost křemíkové architektury:** Pochopení a vyřešení konfliktu Octal SPI PSRAM sběrnice dokazuje hlubokou orientaci v hardwarovém zapojení čipů řady ESP32-S3.

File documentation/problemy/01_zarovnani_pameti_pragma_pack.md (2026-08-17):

# Problém: Zarovnání paměti v binárním UART protokolu (Memory Alignment & Padding)

## Popis problému
Při návrhu mezideskové komunikace mezi dvěma mikrokontroléry (ESP32-S3 a ESP32-WROOM) bylo rozhodnuto přenášet stavové a příkazové balíčky pomocí přímého binárního přenosu C++ struktur přes sběrnici UART (`Serial.write((uint8_t*)&packet, sizeof(packet))`).

Při odesílání struktury obsahující smíšené datové typy (např. 1-bajtový `bool`, 2-bajtový `int16_t` a 4-bajtový `int32_t`) docházelo k chybám v interpretaci dat na straně příjemce – hodnoty proměnných byly posunuté o několik bajtů, tlačítka hlásila nesmyslné stavy a kontrolní součty neseděly.

---

## Příčina problému: Automatický Memory Padding 32bitového procesoru
Architektura procesorů Xtensa (ESP32) je 32bitová. Procesor pro maximalizaci rychlosti přístupu do paměti RAM vyžaduje, aby proměnné začínaly na paměťových adresách, které jsou násobkem jejich velikosti (tzv. **Data Alignment**):
* 1bajtový `bool` / `uint8_t` může začínat na libovolné adrese.
* 2bajtový `int16_t` musí začínat na sudé adrese (násobek 2).
* 4bajtový `int32_t` / `float` musí začínat na adrese dělitelné 4.

Pokud máme ve struktuře definované položky za sebou:
```cpp
struct NesrovnanaStruktura {
    uint8_t  startByte; // 1 bajt (adresa 0x00)
    // --> ZDE KOMPILÁTOR VLOŽÍ 3 NEVIDITELNÉ VÝPLŇOVÉ BAJTY (Padding)!
    int32_t  encoderPos; // 4 bajty (adresa 0x04)
    bool     btnState;   // 1 bajt (adresa 0x08)
    // --> ZDE KOMPILÁTOR VLOŽÍ 1 VÝPLŇOVÝ BAJT!
    uint16_t potValue;   // 2 bajty (adresa 0x0A)
};
```

### Důsledky pro UART přenos:
1. **Přenášení smetí:** `sizeof(NesrovnanaStruktura)` není $1 + 4 + 1 + 2 = 8$ bajtů, ale **12 bajtů**. Po sériové lince se tak posílají náhodné výplňové bajty z paměti RAM.
2. **Nekompatibilita:** Pokud by na druhém procesoru kompilátor zarovnal položky odlišně (např. jiná verze GCC nebo jiná architektura), data se posunou a hodnota `potValue` se přečte z výplňových bajtů namísto skutečných dat.

---

## Řešení: Vynucení 1bajtového zarovnání pomocí `#pragma pack(push, 1)`

Kompilátoru bylo explicitně nařízeno zakázat vkládání výplňových bajtů pro komunikační struktury v souboru `UartProtocol.h`.

```cpp
// 1. Uložíme stávající nastavení a nastavíme zarovnání na těsný 1 bajt
#pragma pack(push, 1)

struct TopToBottomPacket {
    uint8_t  startByte;              // 1 bajt
    uint8_t  currentMode;            // 1 bajt
    bool     overrideAutonomy;       // 1 bajt
    int16_t  targetSmartServoAngle;  // 2 bajty
    uint8_t  targetServoAngle;       // 1 bajt
    int8_t   targetContinuousServo;  // 1 bajt
    int16_t  targetMotorSpeed;       // 2 bajty
    uint32_t ledStrip[8];            // 32 bajtů
    uint8_t  ledBrightness;          // 1 bajt
    char     oledLine1[17];          // 17 bajtů
    char     oledLine2[17];          // 17 bajtů
    uint8_t  checksum;               // 1 bajt
    uint8_t  endByte;                // 1 bajt
};

// 2. Vrátíme standardní optimalizované zarovnání pro zbytek programu
#pragma pack(pop)
```

### Proč `#pragma pack` místo `__attribute__((packed))`?
Oba zápisy vedou ke stejnému výsledku, ale direktiva `#pragma pack(push, 1)` je standardizovaná napříč všemi moderními C/C++ kompilátory (GCC, Clang, MSVC), zatímco `__attribute__((packed))` je specifické rozšíření kompilátoru GCC.

---

## Ochrana proti posunu dat (Resynchronizace přes `peek()`)

Pro případ, že by se během běhu zařízení na lince ztratil bajt (např. odpojení konektoru), byla na straně přijímače implementována synchronizační logika:
```cpp
while (SerialESP.available() >= sizeof(BottomToTopPacket)) {
    // Podíváme se na první bajt v bufferu bez jeho smazání
    if (SerialESP.peek() != UART_FRAME_START_BOTTOM_TO_TOP) {
        SerialESP.read(); // Zahodíme vadný bajt a hledáme začátek 0x55
        continue;
    }
    // Načteme přesně definovaný počet bajtů přímo do struktury
    SerialESP.readBytes((uint8_t*)&inPacket, sizeof(BottomToTopPacket));
    ...
}
```

---

## Výsledný přínos pro projekt
* **100% předvídatelná velikost paketu:** Velikost odpovídá přesnému součtu proměnných.
* **Maximální propustnost:** Žádné přenášení výplňových bajtů po lince.
* **Stabilita:** Odolnost proti posunu rámců a okamžitá resynchronizace linky.

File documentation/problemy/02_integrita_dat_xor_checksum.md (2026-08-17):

# Problém: Zabezpečení integrity dat na sériové lince (XOR Checksum vs. prostý součet)

## Popis problému
Při komunikaci mezi horním panelem (ESP32-S3) a dolním akčním panelem (ESP32-WROOM) dochází k souběžnému provozu výkonových prvků – DC motoru s pulzně šířkovou modulací (PWM), modelářských servomotorů a chytrých sběrnicových serv LX-16A. 

Tyto indukční zátěže způsobují na napájecích i signálových vodičích elektromagnetické rušení (**EMI / EMI spikes**), které může způsobit náhodné otočení logického stavu bitu na sériové lince UART (tzv. **Bit-flip**, kdy se z logické `0` stane `1` nebo naopak).

Pokud by přijímající mikrokontrolér vykonal poškozený příkaz, hrozí:
* Nekontrolovaný trhavý pohyb serva do krajní mechanické polohy (riziko poškození převodů).
* Falešné spuštění motoru na maximální otáčky.
* Zobrazení rozsypaných znaků na OLED displeji.

---

## Proč nestačí prostý součet bajtů (Additive Checksum `5 + 3 + 20`)?

Prvním intuitivním nápadem bylo sečíst všechny bajty paketu a výsledek uložit jako 1bajtový kontrolní součet. Tento přístup však v praxi selhává ze tří důvodů:

### 1. Přetečení 8bitového registru (Integer Overflow)
Náš paket `TopToBottomPacket` obsahuje desítky proměnných (včetně 24 bajtů pro barvy 8 RGB LED diod). Součet všech bajtů paketu běžně dosahuje hodnot okolo **3 500**.
Při uložení do 1 bajtu (`uint8_t`) dochází k oříznutí vyšších řádů:
$$3500 \pmod{256} = 172$$
Většina bitové informace o obsahu zprávy se tímto přetečením ztratí.

### 2. Maskování chyb kvůli přenosu jedničky (Carry bit problem)
Při aritmetickém sčítání dochází k přenosu do vyššího řádu (např. $1 + 1 = 0$, jednička jde dál). Pokud rušení změní bity na dvou různých místech paketu, tyto chyby se mohou aritmeticky vyrušit a výsledný součet zůstane stejný – přijímač poškozený paket nerozpozná.

### 3. Nerozpoznání prohození bajtů
Aritmetické sčítání je komutativní ($A + B = B + A$). Pokud by došlo k záměně sousedních bajtů, prostý součet tuto chybu neodhalí.

---

## Řešení: Bitový kontrolní součet pomocí operace XOR (Exclusive OR)

Jako algoritmus pro ověření integrity byl zvolen **XOR kontrolní součet** (v průmyslu známý jako *Longitudinal Redundancy Check – LRC*).

### Princip fungování XOR na úrovni bitů:
Operace XOR porovnává bity podle pravidla: *„Pokud jsou bity různé, výsledek je 1; pokud jsou stejné, výsledek je 0.“*

| Bit A | Bit B | A XOR B | Význam |
| :---: | :---: | :---: | :--- |
| **0** | **0** | **0** | Stejné stavy |
| **0** | **1** | **1** | Různé stavy |
| **1** | **0** | **1** | Různé stavy |
| **1** | **1** | **0** | Stejné stavy |

### Proč je XOR ideální pro embedded systémy?
1. **Nezávislá parita sloupců:** XOR funguje jako nezávislá kontrola lichosti/sudosti pro každý z 8 bitových sloupců zvlášť. Mezi sloupci nedochází k žádnému přenosu (žádný *carry bit*).
2. **100% detekce jednobitových chyb:** Pokud elektromagnetický impuls otočí jakýkoliv 1 bit v libovolném bajtu celého paketu, výsledné XOR `checksum` se zaručeně změní.
3. **Nikdy nepřeteče:** Výpočet probíhá stále v rozsahu 0 až 255.
4. **Extrémní rychlost:** Operace trvá na procesoru ESP32 pouhý **1 hodinový takt (cca 4 nanosekundy)**.

---

## Implementace v projektu

V souboru `UartProtocol.h` byla definována inline funkce:
```cpp
inline uint8_t calculateChecksum(const uint8_t *data, size_t length) {
    uint8_t crc = 0;
    for (size_t i = 0; i < length; i++) {
        crc ^= data[i]; // Bitový XOR s každým bajtem paketu
    }
    return crc;
}
```

### Použití při odesílání:
```cpp
// Spočítáme checksum ze všech bajtů před kontrolním součtem
outPacket.checksum = calculateChecksum(
    (const uint8_t*)&outPacket, 
    sizeof(TopToBottomPacket) - 2 // Vynecháme samotný checksum a endByte
);
SerialESP.write((const uint8_t*)&outPacket, sizeof(TopToBottomPacket));
```

### Použití při příjmu:
```cpp
uint8_t vypoctenyCRC = calculateChecksum(
    (const uint8_t*)&inPacket, 
    sizeof(BottomToTopPacket) - 2
);

if (inPacket.endByte == UART_FRAME_END && inPacket.checksum == vypoctenyCRC) {
    // Data jsou 100% v pořádku -> bezpečně aplikujeme na hardware
    globalState.updateServo(inPacket.currentServoAngle);
} else {
    // Paket je poškozen rušením -> okamžitě zahazujeme
    Serial.println("[UART] Detekovano ruseni! Paket byl bezpecne ignorovan.");
}
```

---

## Výsledný přínos pro projekt
* **Vysoká odolnost proti rušení:** Žádné nekontrolované cukání servomotorů při spínání zátěže.
* **Nulová režie procesoru:** Výpočet kontrolního součtu celého paketu zabere méně než 0,15 mikrosekundy.
* **Robustní komunikace:** Každý rámec je zkontrolován před provedením jakéhokoliv fyzického pohybu.

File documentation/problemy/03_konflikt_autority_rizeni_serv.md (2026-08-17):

# Problém: Konflikt autority řízení servomotorů v distribuovaném systému (Authority Race Condition)

## Popis problému
V našem projektu je hardware rozdělen na dva samostatné mikrokontroléry:
* **Horní panel (ESP32-S3):** Běží na něm stavový automat, hry a hlavní logika.
* **Dolní panel (ESP32-WROOM):** Jsou k němu fyzicky připojeny akční členy – klasické modelářské servo, chytré servo LX-16A, kontinuální servo a DC motor.

Při návrhu autonomního chování dolního panelu vyvstává zásadní architektonický problém: **Kdo má v daném okamžiku právo rozhodovat o poloze servomotorů?**

---

## Scénář vzniku kolize příkazů (Race Condition)

Představme si situaci v praxi:
1. **Autonomní činnost dolního panelu:** Dolní panel má v určitém režimu možnost reagovat lokálně na svůj analogový potenciometr a otáčet servem na úhel $120^\circ$.
2. **Pravidelná synchronizace z horního panelu:** Horní panel v rámci udržování spojení (tzv. *Heartbeat*) pravidelně každých 200 ms odesílá dolů stavový balíček `TopToBottomPacket`.
3. **Konflikt hodnot:** V tomto balíčku má horní panel uloženou poslední známou hodnotu úhlu serva z dřívější doby (např. $0^\circ$).
4. **Fyzický projev:** 
   * Dolní panel otočí servo na $120^\circ$.
   * O pár milisekund později dorazí z horního panelu příkaz $0^\circ$.
   * Dolní panel servo vrátí na $0^\circ$.
   * V dalším taktu lokální smyčky dolní panel servo opět otočí na $120^\circ$.

> **Výsledek:** Servomotor se dostane do stavu permanentního kmitání (**jittering / hunting**), dochází k mechanickému namáhání převodů, nadměrnému proudovému odběru a zahřívání motorku.

---

## Analýza podstaty problému

Tento jev je v robotice a distribuovaných řídicích systémech známý jako **Konflikt autority (Conflict of Authority)** neboli **Nedodržení jediného zdroje pravdy (Single Source of Truth violation)**.

K problému dochází proto, že o stejný fyzický akční člen usilují dva nezávislé řídicí procesy běžící na dvou oddělených procesorech bez přesně definované hierarchie řízení.

---

## Možné teoretické přístupy k řešení

Pro finální implementaci se zvažují následující přístupy:

### 1. Hierarchické řízení podle globálního módu (`AppMode`)
Autorita je pevně svázána s aktuálním stavem stavového automatu:
* V režimech her (`MODE_GAME_SNAKE`, `MODE_GAME_FLAPPY`) má dolní panel plnou autonomii – příkazy z horního panelu ignoruje a slouží pouze jako odesílatel telemetrie.
* V testovacích a manuálních režimech (`MODE_SERVA`, `MODE_MOTOR`) přebírá absolutní autoritu horní panel a dolní panel pouze vykonává příkazy.

### 2. Explicitní příznak převzetí řízení (`overrideAutonomy`)
V datovém paketu je vyhrazen boolean příznak:
* `overrideAutonomy = false` $\rightarrow$ Dolní panel řídí akční členy lokálně.
* `overrideAutonomy = true` $\rightarrow$ Dolní panel poslouchá hodnoty `targetServoAngle` z horního panelu.

### 3. Rezervovaná hodnota „Neřídit / Pasivní stav“ (Sentinel value)
Pokud horní panel nechce do řízení zasahovat, pošle v paketu neplatný úhel (např. `targetServoAngle = 255`, přičemž rozsah serva je $0–180^\circ$). Dolní panel tuto hodnotu interpretuje jako pokyn k zachování vlastní lokální logiky.

---

## Shrnutí pro text maturitní práce
Správné rozdělení autority je základním předpokladem stability distribuovaného systému. Bez jednoznačně definovaného rozhraní, které určuje, zda je akční člen řízen centrálně (Master) nebo lokálně (Slave), dochází k nebezpečným kolizím řídicích signálů.

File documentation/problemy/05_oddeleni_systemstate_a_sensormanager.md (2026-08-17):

# Problém: Architektonické oddělení datové a hardwarové vrstvy (SystemState vs. SensorManager)

## Popis problému
Při vývoji komplexního vestavěného systému s více než 15 senzory a akčními členy hrozí vznik tzv. **„Božské třídy“ (God Object Antipattern)**. 

Původní návrh směřoval k tomu, že třída `SystemState` měla kromě správy sdílené paměti a FreeRTOS mutexů provádět i samotné čtení hardwarových pinů, inicializaci I2C sběrnic a generování tónů bzučáku.

### Rizika spojení dat a hardware do jedné třídy:
1. **Porušení principu jedné odpovědnosti (Single Responsibility Principle):** Třída má více důvodů ke změně – změna komunikačního protokolu i výměna fyzického pinu by vyžadovala zásah do stejného souboru.
2. **Nebezpečné zamykání mutexů:** Pokud by funkce čtoucí pomalý senzor (např. DHT11 nebo ultrazvuk `pulseIn()`, který trvá až 30 ms) držela zámek mutexu, došlo by k okamžitému zablokování vykreslování displeje i webového serveru.
3. **Obtížná testovatelnost a simulace:** Bez oddělení hardware nelze snadno spustit demo simulátor her bez fyzicky připojených čidel.

---

## Řešení: Dvojvrstvá architektura (State Layer vs. Hardware Layer)

Systém byl striktně rozdělen do dvou nezávislých vrstev:

```text
+-------------------------------------------------------------+
|                      APLIKAČNÍ VRSTVA                       |
|          (Hry, Grafické UI, Stavový automat, Web)           |
+-------------------------------------------------------------+
                              |
                              v
+-------------------------------------------------------------+
|                 1. DATOVÁ VRSTVA (SystemState)              |
|  - Čistý datový model (SensorData)                          |
|  - Thread-Safe přístup pomocí FreeRTOS Mutexu               |
|  - ŽÁDNÝ přímý přístup k fyzickým pinům a registrům         |
|  - Bleskové atomické operace (trvání < 0,05 µs)             |
+-------------------------------------------------------------+
                              ^
                              | (aktualizuje data)
+-------------------------------------------------------------+
|              2. HARDWAROVÁ VRSTVA (SensorManager)           |
|  - Přímé ovládání GPIO, I2C sběrnic, časovačů a SPI         |
|  - Fyzické čtení: DHT, VL53L0X, HC-SR04, TCS34725, LSM6DS3  |
|  - Fyzické výstupy: LED diody, bzučák, 74HC595, WS2812B     |
|  - Automatická aktualizace stavu v SystemState po akci      |
+-------------------------------------------------------------+
```

---

## Rozdělení rolí v kódu

### 1. `SystemState` (Správce dat a synchronizace)
Spravuje pouze paměťovou strukturu `SensorData` a zajišťuje, že čtení a zápis mezi jádry Core 0 a Core 1 je bezpečný:
```cpp
void updateTemperature(float temp, float hum) {
    if (xSemaphoreTake(stateMutex, (TickType_t)10) == pdTRUE) {
        sensors.temperature = temp;
        sensors.humidity = hum;
        xSemaphoreGive(stateMutex);
    }
}
```

### 2. `SensorManager` (Fyzický ovladač)
Zajišťuje komunikaci s fyzickým hardwarem a okamžitě zapisuje výsledek do `globalState`:
```cpp
void SensorManager::readDHT() {
    float t = dht.readTemperature();
    float h = dht.readHumidity();
    if (!isnan(t) && !isnan(h)) {
        globalState.updateTemperature(t, h); // Zápis do datové vrstvy
    }
}

void SensorManager::setLed1(bool on) {
    digitalWrite(PIN_LED1, on ? HIGH : LOW); // Fyzická akce
    globalState.updateLeds(on, current.led2, current.led3); // Uložení stavu
}
```

---

## Výsledný přínos pro projekt
* **Jediný zdroj pravdy (Single Source of Truth):** Displej a hry se nikdy neptají přímo pinů čidel, ale čtou jednotnou strukturu `SensorData`.
* **Minimální doba držení mutexu:** Mutex je zamčen pouze na desítky nanosekund při zápisu/čtení z RAM.
* **Čistý a modulární kód:** Výměna hardwarového pinu nebo typu čidla ovlivní pouze `SensorManager`, zatímco grafika a herní logika zůstává netknutá.

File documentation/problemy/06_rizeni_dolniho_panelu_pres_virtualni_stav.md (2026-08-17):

# Problém: Řízení periferií dolního panelu čistě přes virtuální stav v SystemState

## Popis problému
Horní panel (ESP32-S3) slouží jako hlavní mozek zařízení, kde běží uživatelské rozhraní, menu i hry. Uživatel však potřebuje z těchto aplikací ovládat periferie, ke kterým **z horní desky nevedou žádné fyzické vodiče** – například:
* Změnit úhel servomotoru na dolním panelu.
* Nastavit rychlost DC motoru.
* Změnit barvu nebo jas 8-LED WS2812B pásku na dolní desce.
* Vypsat text na 0.96" OLED displej dolního panelu.

Pokud by každá hra nebo položka menu musela napřímo otevírat sériovou linku, sestavovat UART pakety a řešit komunikační chyby, došlo by k extrémnímu provázání kódu (**Tight Coupling**) a aplikační logika by byla zahlcena nízkoúrovňovou komunikací.

---

## Řešení: Abstrakce hardware přes virtuální stavový model (Decoupling)

Řešením bylo zavést **koncept virtuálního hardwarového stavu** uvnitř centrální struktury `SensorData`.

Pro herní logiku nebo menu se periferie dolního panelu tváří úplně stejně jako lokální proměnné:
1. Aplikační kód zavolá standardní setter v `SystemState`.
2. Setter zapíše hodnotu do virtuálního stavu v paměti RAM a **automaticky zvedne příznak `bottomNeedsTx = true`**.
3. O samotné fyzické doručení po drátech UART se transparentně na pozadí postará FreeRTOS úloha `Task_UART` běžící na jádře Core 0.

---

## Architektonické schéma toku dat

```text
[ Herní logika / Menu na Core 1 ]
               |
               | 1. Volání: globalState.updateServo(90);
               v
[ SystemState (Stav v RAM) ]
   - sensors.servoAngle = 90;
   - bottomNeedsTx = true;  <--- Automatické zvednutí příznaku
               |
               | 2. Přečtení příznaku ve smyčce (Core 0)
               v
[ Task_UART na Core 0 ]
   - Sestavení paketu TopToBottomPacket
   - Výpočet kontrolního součtu
   - SerialESP.write(...)
               |
               | 3. Fyzický přenos UART (2.6 ms)
               v
[ Dolní panel (ESP32-WROOM) ]
   - Nastavení PWM signálu pro servo na 90°
```

---

## Ukázka implementace v kódu

### 1. Setter v `SystemState.h`:
```cpp
void updateServo(uint8_t angle) {
    if (xSemaphoreTake(stateMutex, (TickType_t)10) == pdTRUE) {
        sensors.servoAngle = angle;
        bottomNeedsTx = true; // Automaticky upozorníme UART vlákno
        xSemaphoreGive(stateMutex);
    }
}
```

### 2. Použití v aplikační vrstvě (např. v menu nebo hře):
```cpp
// Uživatel pohnul kurzorem v menu servomotorů:
globalState.updateServo(120); 

// Kód hry nemusí vědět, že servo je připojeno na jiném čipu přes UART!
```

---

## Výhody tohoto přístupu pro projekt

1. **Čistota kódu (Separation of Concerns):** Grafické rozhraní a herní logika se starají pouze o data, nikoliv o přenosové protokoly a baudové rychlosti.
2. **Okamžitá zpětná vazba pro UI:** Displej na horním panelu okamžitě zobrazí novou hodnotu úhlu serva z paměti RAM (latence < 0,1 µs), zatímco UART přenos probíhá asynchronně na pozadí.
3. **Snadná simulace:** V testovacím režimu bez připojeného dolního panelu funguje celé grafické menu beze změny kódu.

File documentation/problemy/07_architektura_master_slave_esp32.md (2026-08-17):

# Architektura: Rozdělení Master-Slave mezi dvěma mikrokontroléry ESP32

## Popis architektury
Projekt ESP-Demo-Box využívá pro řízení celého systému dva nezávislé mikrokontroléry:
* **Horní panel (Master):** Výkonnější čip **ESP32-S3 DevKitC** (dvoujádrový procesor Xtensa LX7 @ 240 MHz, podpora vektorových instrukcí, velká SRAM).
* **Dolní panel (Slave / I/O expandér):** Osvědčený čip **ESP32-WROOM** (dvoujádrový procesor Xtensa LX6 @ 240 MHz).

Tyto dvě jednotky jsou propojeny vysokorychlostní plně duplexní sériovou linkou UART (piny TX/RX) a tvoří distribuovaný vestavěný systém.

---

## Proč je rozdělení na Master a Slave výhodné?

Použití dvou spolupracujících mikrokontrolérů namísto jediného centralizovaného čipu přináší několik zásadních technických výhod:

### 1. Dostatek GPIO pinů pro všechny moduly
ESP-Demo-Box obsahuje dohromady více než 25 různých senzorů, akčních členů, displejů a tlačítek. Žádný běžný mikrokontrolér nemá dostatek vyvedených fyzických pinů, aby obsloužil:
* 2.8" SPI grafický displej ST7789,
* 0.96" I2C OLED displej, I2C LCD 1602, sedmisegmentový displej přes 74HC595,
* Dvě oddělená I2C rozhraní pro senzory (VL53L0X, LSM6DS3, TCS34725),
* Dva nezávislé 8-LED WS2812B pásky (vyžadující přesné časování RMT/DMA),
* Servomotory, DC motor s PWM, rotační enkodér, analogový joystick a tlačítka.

Rozdělením na dvě desky má každé ESP k dispozici dostatek dedikovaných GPIO pinů bez nutnosti složitých externích multiplexerů.

---

### 2. Oddělení výpočetně náročné grafiky od přesného generování signálů
* **Horní panel (Master):** Vykreslování her a animací v rozlišení $320 \times 240$ v 16bitových barvách (Double Buffering) alokuje 153,6 KB RAM a vytěžuje SPI sběrnici na vysokých frekvencích (40–80 MHz). K tomu běží Wi-Fi AP a asynchronní webový server.
* **Dolní panel (Slave):** Generuje přesné PWM pulzy pro servomotory (50 Hz), obsluhuje přerušení z rotačního enkodéru a čte ADC převodníky.

> **Výhoda:** Vykreslování grafiky nebo síťová komunikace na horním panelu **nikdy nezpůsobí zpoždění generování PWM pulzů pro serva**, což eliminuje jakékoliv chvění (*jitter*) motorů.

---

### 3. Logické rozdělení rolí a odpovědnosti

| Vlastnost | Horní panel (Master / Mozek) | Dolní panel (Slave / I/O podsystém) |
| :--- | :--- | :--- |
| **Čip** | ESP32-S3 | ESP32-WROOM |
| **Primární role** | Uživatelské rozhraní, logika, hry, web | Fyzické rozhraní, čtení vstupů, výkonové řízení |
| **Vstupy** | DHT, lasery, ultrazvuk, barvy, IMU | Joystick, 5 tlačítek, enkodér, potenciometr, 2 switche |
| **Výstupy** | 2.8" TFT displej, 3x LED, bzučák, 7-seg | Servomotory, DC motor, 0.96" OLED, spodní LED pásek |
| **Komunikace** | Wi-Fi WebServer + UART Master | UART Slave |

---

## Princip spolupráce po sběrnici UART

1. **Směr Dolní $\rightarrow$ Horní (Telemetrie):**  
   Dolní panel nepřetržitě čte své vstupy (joystick, tlačítka, přepínače) a posílá kompletní balíček `BottomToTopPacket` nahoru do mozku systému.
2. **Směr Horní $\rightarrow$ Dolní (Řídicí příkazy):**  
   Horní panel vyhodnocuje stav her a uživatelského menu. Při změně odešle balíček `TopToBottomPacket` s požadovanými úhly serv, rychlostí motoru, textem pro OLED nebo barvami LED pásku.

---

## Shrnutí pro text maturitní práce
Architektura Master-Slave představuje moderní modulární přístup k návrhu vestavěných systémů. Umožňuje izolovat výkonově náročné akční členy a mechanické ovládací prvky na dedikovaném periferním řadiči (Slave), zatímco hlavní procesor (Master) se plně soustředí na grafické rozhraní, herní algoritmy a síťovou konektivitu.

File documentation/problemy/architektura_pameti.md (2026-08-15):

# Problém: Rozdělení paměťového prostoru a práce s grafikou

## Popis situace
V tradičním pojetí programování začátečníci často považují veškerou fyzicky dostupnou paměť za jeden sdílený prostor, do kterého mohou ukládat proměnné a číst z něj napříč celým zařízením.

V architektuře výukového kufru jsou přítomny dva zcela nezávislé čipy (ESP32-S3 a ESP32), z nichž každý disponuje vlastní oddělenou operační pamětí (SRAM). Navíc samotný hlavní čip ESP32-S3 disponuje další externí pamětí (16 MB PSRAM). Je nutné přesně definovat, jaká data žijí ve které paměti.

## Architektonické řešení: Definice hranic a alokace
Základním architektonickým pravidlem je absolutní izolace sdíleného stavového prostoru.

1. **Izolace Master-Slave:** Globální stavový objekt (`SystemState`), který definuje, v jakém režimu se systém nachází a jaká jsou aktuální naměřená data, existuje **výlučně v operační paměti RAM na horním panelu** (Master). Spodní panel o tomto prostoru nemá žádné fyzické povědomí a přistupuje k němu výhradně formou zprostředkovaných UART paketů (požadavek na změnu).
2. **Eliminace fragmentace RAM pomocí PSRAM:** Běžná operační paměť mikrokontroléru má velmi omezenou kapacitu (cca 500 KB). Kdyby se rozsáhlé grafické prvky displeje (Framebuffery) nebo webové HTML stránky načítaly do běžných C++ proměnných typu `String`, došlo by k rychlé fragmentaci a vyčerpání haldy (Heap), což vede k pádu systému. Projekt proto vyčleňuje využití externí 16 MB velké PSRAM. Rozbalování JPG obrázků a renderování grafiky z LittleFS je směřováno prostřednictvím DMA (Direct Memory Access) striktně do této PSRAM, čímž zůstává rychlá interní SRAM zcela uvolněna pro rychlé vlákna FreeRTOS a matematické výpočty.

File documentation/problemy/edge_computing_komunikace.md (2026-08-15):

# Problém: Vytížení sběrnice a latence při řízení (Edge Computing)

## Popis situace
V tradičním pojetí Master-Slave architektury funguje Slave (spodní panel) pouze jako pasivní sběrač dat. Neustále čte všechny senzory, joysticky a tlačítka a nepřetržitě je odesílá Masteru (hornímu panelu). Master data vyhodnotí a pošle zpět příkazy (např. "Otoč servem o 5 stupňů").

Tento přístup generuje závažné problémy:
1. **Zahlcení UART sběrnice:** Neustálé posílání stovek zpráv za vteřinu zatěžuje sběrnici zbytečným balastem i v době, kdy zařízení například jen "stojí" v menu.
2. **Vysoká latence (Zpoždění):** Dráha signálu (Potenciometr -> Slave -> UART -> Master -> Zpracování -> UART -> Slave -> Motor) způsobuje nechtěné záseky a prodlevy v plynulém pohybu.

## Architektonické řešení: Distribuovaná logika a obousměrná vazba
Systém nevyužívá spodní desku jen jako klávesnici, ale přesouvá část rozhodovací logiky přímo k senzorům a motorům – tento princip se označuje jako **Edge Computing**.

Toto je umožněno díky obousměrné (Full-Duplex) UART komunikaci. Kdykoliv dojde na horním (Master) panelu ke změně globálního stavu (např. uživatel vybere režim "Test motorů"), Master odešle tento stav dolů.

### Přínosy řešení v praxi:
* **Filtrování dat (Odlehčení sběrnice):** Pokud spodní panel (díky zprávě z vrchu) ví, že se systém nachází v režimu "Hlavní Menu", záměrně přestane odesílat data z analogového joysticku, protože ví, že by je Master stejně zahodil.
* **Hardwarová akcelerace s nulovou latencí:** Jakmile systém přejde do režimu "Test motorů", spodní panel začne interně mapovat vstup z potenciometru přímo na PWM výstup motoru. Řídicí smyčka běží lokálně na spodním čipu. K hornímu čipu se přes UART posílá už jen "informační občasník" o poloze serva za účelem překreslení grafiky na displeji. Zpoždění ovládání motorů je tak zcela eliminováno.
* **Autonomie OLED displeje:** Spodní panel může dynamicky měnit instrukce na svém lokálním displeji přesně na základě toho, jaký stav mu nadiktoval Master, čímž zlepšuje celkový UX (User Experience).

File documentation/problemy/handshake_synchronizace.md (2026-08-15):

# Problém: Synchronizace bootování dvou nezávislých mikrokontrolérů

## Popis situace
Architektura výukového kufru je fyzicky rozdělena mezi dva nezávislé čipy:
1. **Spodní panel (ESP32-WROOM-32D)** – Zpracovává pouze lokální periferie a bootuje velmi rychle (v řádu milisekund).
2. **Horní panel (ESP32-S3)** – Působí jako Master (hlavní mozek). Obsluhuje Wi-Fi připojení, inicializuje TFT displej a senzory, což způsobuje, že jeho bootovací sekvence je nepoměrně delší (v řádu sekund).

Pokud by spodní panel okamžitě po startu začal odesílat data nebo vykonávat řídicí povely, hrozila by desynchronizace, ztráta dat, a v nejhorším případě neřízený a nebezpečný pohyb připojených servomotorů.

## Architektonické řešení: Boot Handshake
Tento problém je vyřešen implementací synchronizační sekvence zvané "Handshake" (potřesení rukou) realizované přes obousměrnou sběrnici UART.

1. **Fáze čekání (Slave):** Spodní ESP32 ihned po rychlém nabootování zablokuje veškeré výkonné hardwarové periferie (motory) a přejde do pasivního režimu. V pravidelných intervalech (např. 500 ms) odesílá na UART sběrnici signál `[SYS_READY]`.
2. **Fáze potvrzení (Master):** Horní ESP32-S3 po dokončení své zdlouhavé inicializace (připojení Wi-Fi, grafika) záměrně vyprázdní sériový buffer, čímž zahodí případný šum z bootování, a přejde do režimu poslechu. Jakmile zachytí signál `[SYS_READY]`, odesílá zpět potvrzovací povel `[START_WORK]`.
3. **Fáze exekuce:** Po přijetí povelu `[START_WORK]` oba mikrokontroléry paralelně a plně synchronizovaně odblokují své procesy a zahájí hlavní programové smyčky. 

Tímto mechanismem je garantováno, že distribuovaný systém vždy startuje jako jeden ucelený a bezpečný stroj bez ohledu na to, jak dlouho trvá připojení k Wi-Fi síti.

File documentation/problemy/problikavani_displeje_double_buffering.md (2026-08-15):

# Problém: Problikávání TFT displeje ST7789 při vykreslování her

## Popis problému
Při vykreslování her (Snake, Flappy Bird) na 2.8" TFT displeji ST7789 ($320 \times 240$ px) docházelo při obnovování obrazu k výraznému problikávání (**flickering**) a trhání obrazu (**screen tearing**). Problém byl obzvláště patrný u hry Flappy Bird při pohybu překážek (trubek) a ptáčka.

## Příčina problému
Při přímočarém vykreslování (Direct Rendering) na displej přes rozhraní SPI se v každém snímku hry prováděly tyto kroky:
1. `display->fillScreen(CYAN)` – Smazání celé obrazovky na modrou barvu pozadí.
2. `display->fillRect(...)` – Nakreslení objektů (ptáček, překážky).

Sběrnice SPI posílá data na displej postupně:
- Displej $320 \times 240$ v 16bitovém barevném režimu (RGB565, 2 B na pixel) vyžaduje na jeden celý snímek:
  $$320 \times 240 \times 2 \text{ B} = 153\,600 \text{ B} \approx 153,6 \text{ KB dat}$$
- Při volání `fillScreen()` poslal procesor příkaz překreslit všech 76 800 pixelů na modro.
- Displej se na malý okamžik stával zcela prázdnou modrou plochou (bez herních prvků).
- Následně se přes SPI posílaly příkazy pro nakreslení žlutého ptáčka a zelených trubek.

Lidské oko registrovalo právě tento krátký mezistav se smazaným pozadím, což způsobovalo nepříjemné blikání.

---

## Řešení: Double Buffering (Dvojitý obrazový buffer)

Místo přímého zápisu na displej v průběhu vykreslování byl v souboru `GameEngine` (`src/hry/game_engine.h`) implementován **Double Buffering** pomocí třídy `GFXcanvas16` z knihovny `Adafruit_GFX`.

### Principy fungování:
1. **Front Buffer (Fyzický displej):** Displej zobrazuje předchozí kompletní snímek a jeho obsah se nemění, dokud není nový snímek plně připraven.
2. **Back Buffer (Canvas v RAM):** V paměti SRAM čipu ESP32-S3 se alokuje virtuální plátno o velikosti $320 \times 240$ pixelů (pole `uint16_t buffer[76800]`).
3. **Kreslení do RAM:** Všechny vykreslovací operace (`clearScreen()`, `fillRect()`, `drawText()`) se provádí bleskově přímo v operační paměti RAM na frekvenci procesoru 240 MHz (záležitost mikrosekund).
4. **Atomický přenos na displej:** Až po dokončení celého snímku se v metodě `GameEngine::displayFrame()` zavolá:
   ```cpp
   display->drawRGBBitmap(0, 0, canvas->getBuffer(), 320, 240);
   ```
   Tím se celý nový obraz přenese z RAM na fyzický displej v jediném plynulém datovém bloku.

---

## Paměťová náročnost na ESP32-S3

- **Potřebná paměť pro Framebuffer (320x240 RGB565):** 153,6 KB RAM.
- **Dostupná paměť čipu ESP32-S3:** 328 KB interní SRAM + 8 MB external PSRAM.
- **Výsledek:** Alokace 153,6 KB pro plynulý Double Buffering využívá cca 6 % celkové paměti flash/RAM a ESP32-S3 ji zvládá bez jakéhokoliv omezení výkonu.

---

## Výsledný efekt
- Úplné odstranění problikávání (0% flickering).
- Plynulý snímkový kmitočet bez trhání obrazu.
- Kód hry zůstal čistý a plně odstíněný od nízkoúrovňové obsluhy displeje.

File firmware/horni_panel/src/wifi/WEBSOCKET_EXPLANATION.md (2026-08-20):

# Jak funguje WebSocket a Fyzika Wi-Fi Přenosu (ESP-Demo-Box)

Tento dokument vysvětluje **WebSocket i fyzikální podstatu Wi-Fi přenosu od naprostých základů**: proč vznikl, jak se inicializuje na ESP32 i na mobilu, jak fungují rádiové vlny na 2.4 GHz a jak probíhá balení, přenos a dekódování dat.

---

## 1. Příběh WebSocketu: Proč a jak vlastně vznikl?

### Starý svět (HTTP požadavky / 1995–2005)
Když vznikal internet, webové stránky byly statické (jako papírové noviny). Prohlížeč poslal dotaz (*"Dej mi stránku"*), server odpověděl a **spojení se okamžitě ukončilo**.

Když v letech 2005+ vznikly živé chatovací aplikace nebo burzovní grafy, vývojáři museli používat škaredý trik zvaný **AJAX Polling**:
> Mobil se každou vteřinu dokola ptal serveru: *"Máš novou zprávu? ... Máš novou zprávu?"*  
> Server 99 % času odpovídal: *"Ne, nemám ... Ne, nemám ..."*

Tento způsob hrozně přetěžoval síť i servery, protože každá otázka i odpověď vyžadovala vytvoření nového TCP spojení a odeslání stopek HTTP hlaviček (cca 500–800 bajtů).

### Vynález WebSocketu (Roku 2011 / Standard RFC 6455)
Skupina síťových inženýrů vymyslela nový protokol **WebSocket (`ws://` nebo šifrovaný `wss://`)**:
* **Myšlenka:** Zastavit neustále zaklepávání na dveře a vytvořit **trvalou otevřenou přímou linku (potrubí)** mezi klientem a serverem.
* **Jak začíná:** Spojení začne jako běžný HTTP požadavek na portu 80. Mobil ale pošle speciální přání: *"Chci upgradovat toto spojení na WebSocket."*
* **Handshake (Podání ruky):** Server odpoví síťovým kódem `101 Switching Protocols` (Přepínám protokoly).
* **Od této chvíle se spojení NEzavírá.** Zůstává otevřený plně duplexní (obousměrný) kanál nad protokolem TCP. Oba účastníci mohou kdykoliv bez ptaní poslat druhovému data. Režie zprávy klesla ze 700 bajtů na **pouhé 2 bajty**!

---

## 2. Jak se WebSocket inicializuje (ESP32 vs. Mobil)

```
+------------------------------------+          +------------------------------------+
|       ESP32 (C++ Backend)          |          |     MOBIL (JavaScript Frontend)    |
|                                    |  Wi-Fi   |                                    |
| 1. AsyncWebSocket ws("/ws");       | <======> | 1. ws = new WebSocket("ws://..."); |
| 2. ws.onEvent(onWebSocketEvent);   | WebSocket| 2. ws.onmessage = handleTelemetry; |
+------------------------------------+          +------------------------------------+
```

### A) Inicializace na ESP32 (C++ / `WebManager.cpp`)
1. **Deklarace objektu (`WebManager.h`):**
   ```cpp
   AsyncWebSocket ws("/ws"); // Vytvoříme objekt WebSocketu naslouchající na adrese "/ws"
   ```
2. **Registrace obsluhy událostí (`WebManager.cpp`):**
   ```cpp
   void WebManager::setupWebSocket() {
       // Říkáme ESP32: Kdykoliv se na kanálu /ws cokoliv stane, zavolej naši funkci onWebSocketEvent!
       ws.onEvent([this](AsyncWebSocket *server, AsyncWebSocketClient *client, 
                         AwsEventType type, void *arg, uint8_t *data, size_t len) {
           this->onWebSocketEvent(server, client, type, arg, data, len);
       });
       server.addHandler(&ws); // Připojíme WebSocket k webovému serveru na portu 80
   }
   ```

### B) Inicializace v Mobilu (JavaScript / `script.js`)
1. **Otevření spojení (`script.js`):**
   ```javascript
   const wsUrl = `ws://${location.host}/ws`; // Sestaví adresu: ws://192.168.4.1/ws
   ws = new WebSocket(wsUrl); // Mobil ihned odesílá žádost o spojení do ESP32
   ```
2. **Nastavení reaktorů na události (`script.js`):**
   ```javascript
   ws.onopen = () => { console.log("Online!"); };
   ws.onmessage = (event) => {
       const data = JSON.parse(event.data); // Rozbalíme JSON text
       handleTelemetry(data);               // Přepíšeme čísla v HTML
   };
   ws.onclose = () => { scheduleReconnect(); };
   ```

---

## 3. Fyzikální podstata přenosu: Od paměti k elektřině a rádiovým vlnám

Sledujme příklad: **ESP32 naměřilo teplotu 23.5 °C a posílá ji na mobil.**

### KROK 1: Z čísla v paměti na bajty (Nuly a jedničky)
V paměti RAM procesoru ESP32 vytvoříme textový řetězec: `"{"t":23.5}"`.  
Každý znak je v paměti zapsán pomocí 8 bitů (1 bajt):
* Znak `{` = `01111011`
* Znak `"` = `00100010`
* Znak `t` = `01110100`
* Znak `:` = `00111010`
* Znak `2` = `00110010`
* Znak `3` = `00110011`
* Znak `.` = `00101110`
* Znak `5` = `01110101`
* Znak `}` = `01111101`

V tranzistorech ESP32 znamená `0` napětí 0 V a `1` napětí 3.3 V.

---

### KROK 2: Fyzika v anténě ESP32 (Rozkmitání elektronů)
1. Síťový Wi-Fi čip vezme tyto nuly a jedničky a pustí je do vysokofrekvenčního vysílače (RF modemu).
2. Vysílač pustí do měděné antény **střídavý elektrický proud kmitající na frekvenci 2.4 GHz (2 412 000 000 kmitů za sekundu)**.
3. **Fyzikální děj v anténě:** V kovu antény jsou volné **elektrony** (záporné náboje). Střídavý proud nutí tyto elektrony v anténě kmitat sem a tam 2,4 miliardkrát za sekundu!

---

### KROK 3: Vznik Elektromagnetické vlny
Podle Maxwellových zákonů elektrodynamiky:
* Pohybující se elektrický náboj (elektron) vytváří **měnící se elektrické pole ($E$)**.
* Měnící se elektrické pole vyvolá **měnící se magnetické pole ($B$)**.
* Tato navzájem se svázaná pole se odtrhnou od antény a vyrazí do prostoru jako **ELEKTROMAGNETICKÁ VLNA**.

* **Rychlost:** Vlna letí vzduchem rychlostí světla ($300\ 000\ \text{km/s}$). Vzdálenost 2 metry uletí za neskutečných $6.7\text{ nanosekund}$.
* **Vlnová délka ($\lambda$):** Při frekvenci 2.4 GHz má jedna vlna délku celkem **12.4 cm**.

---

### KROK 4: Příjem v mobilu a dekódování
1. Vlna dorazí k mobilu a narazí do jeho kovové antény.
2. **Elektromagnetická indukce:** Vlna zatlačí na elektrony v anténě mobilu a **rozkmitá je ve stejném rytmu (2.4 GHz)**. V anténě mobilu vznikne mikro-proud.
3. Wi-Fi modem v mobilu tento mikroproud přečte, demoduluje nuly a jedničky a poskládá text `"{"t":23.5}"`.
4. JavaScript v mobilu přes `JSON.parse` přečte `23.5` a rozsvítí pixely na displeji telefonu!

---

## 4. Časté fyzikální otázky a záhady (Zajímavosti)
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

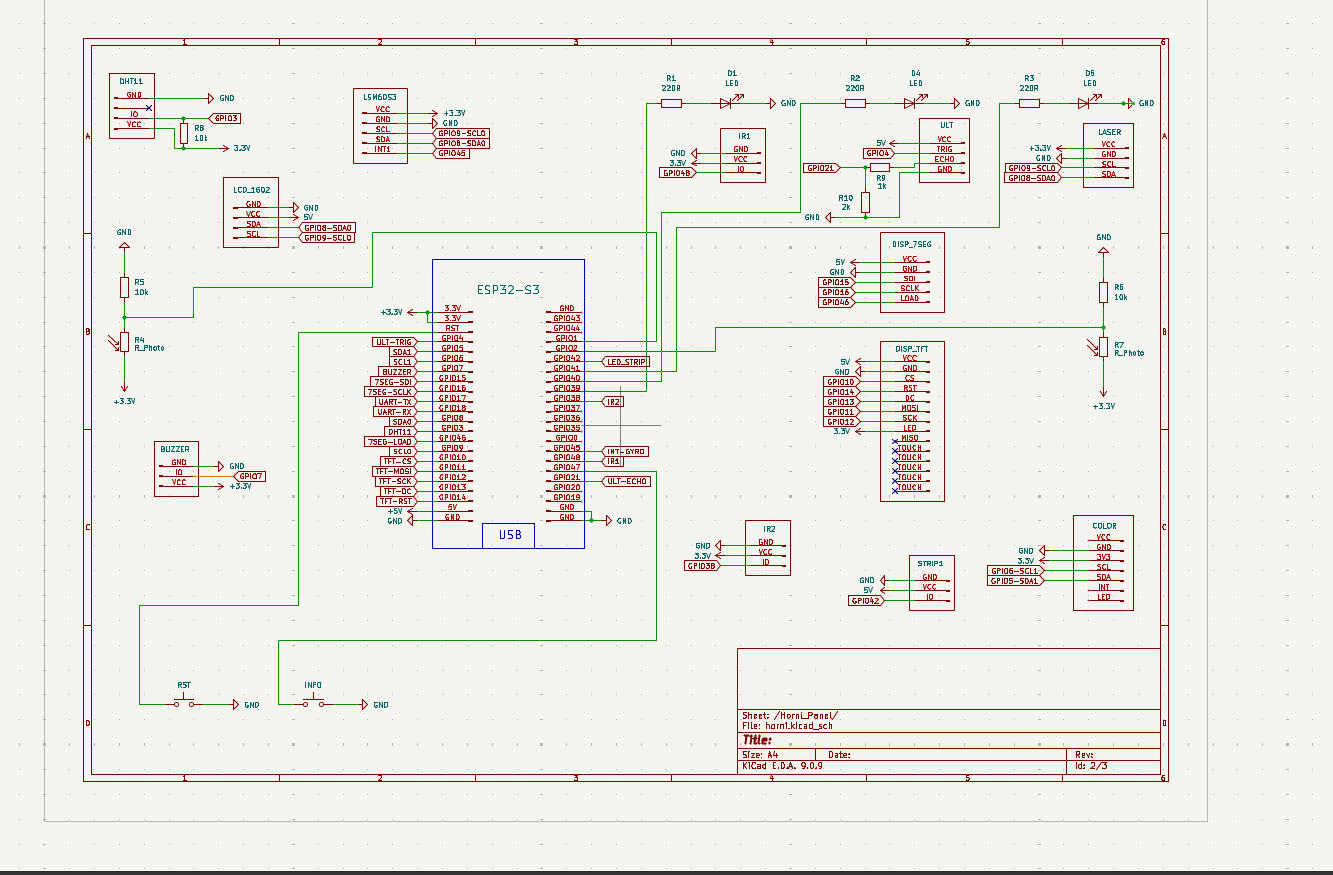
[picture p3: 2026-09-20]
documentation/zapojeni_horni.png

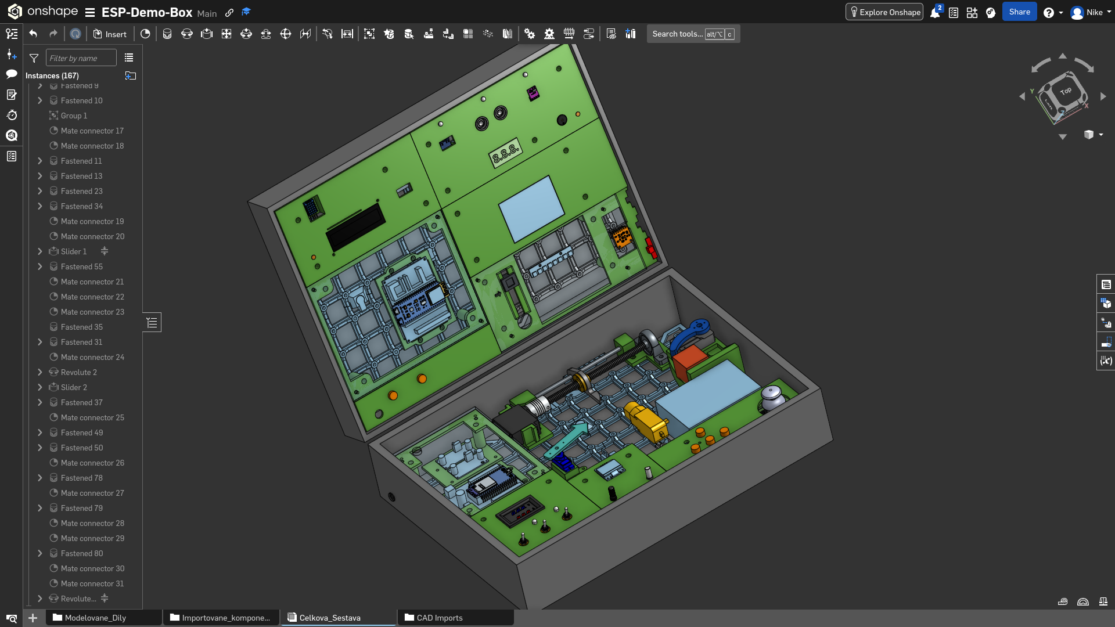
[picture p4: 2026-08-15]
documentation/Snímek obrazovky z 2026-08-09 14-38-21.png

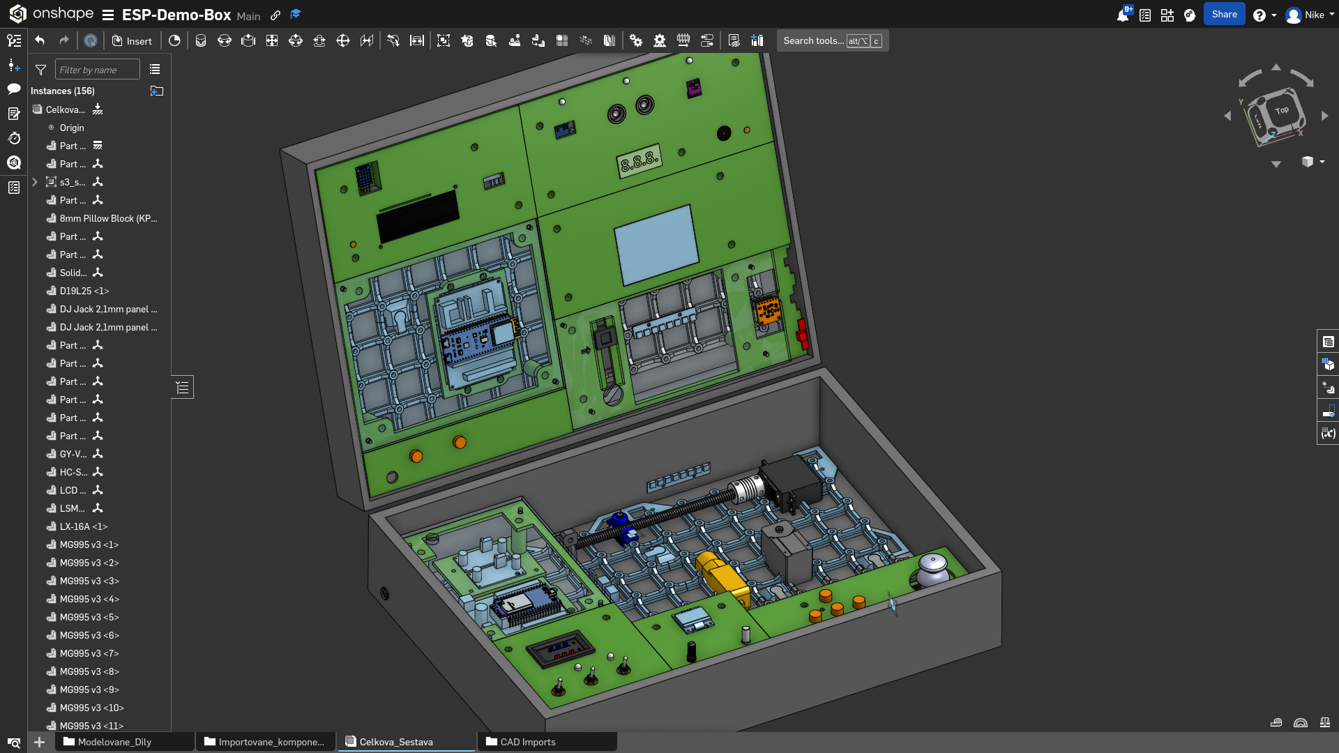
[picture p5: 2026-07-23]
documentation/Snímek obrazovky z 2026-07-16 23-45-03.png

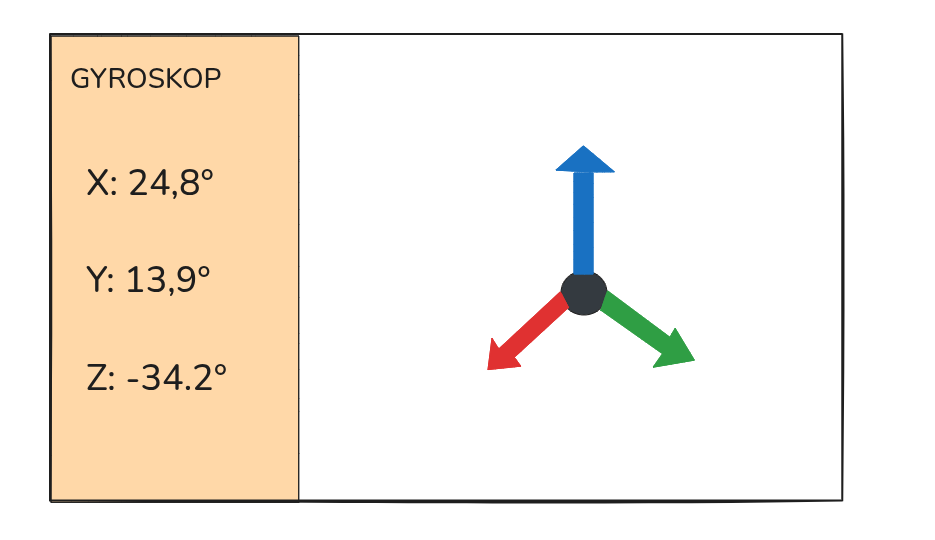
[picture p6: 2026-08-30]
documentation/gyro.png

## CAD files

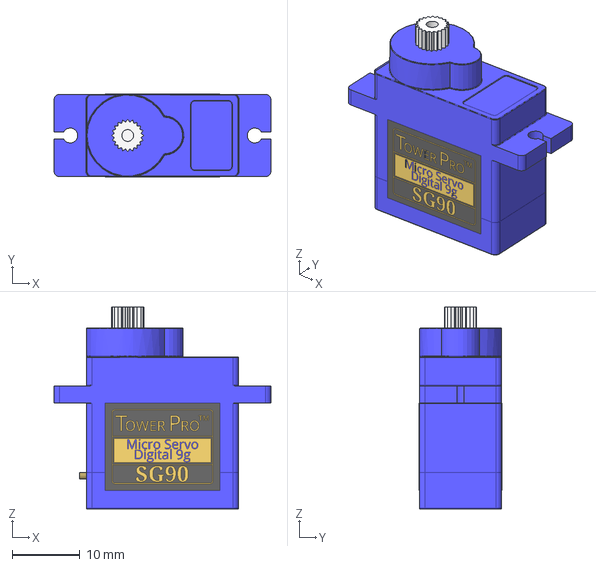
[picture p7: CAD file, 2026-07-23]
hardware/3D/SG90 Servo Assembly.step
32.1 x 12.2 x 29.9 mm
Spline
Servo Case

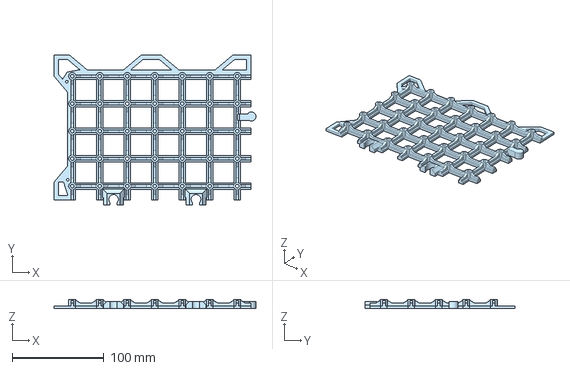
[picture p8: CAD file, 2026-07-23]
hardware/3D/modelovane/drzak_dolni/drzak_dolni_1.step
220.5 x 163.5 x 10.0 mm

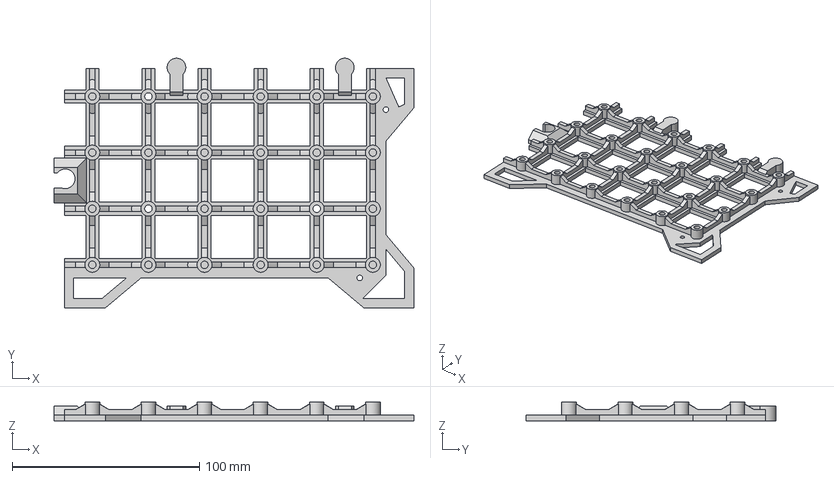
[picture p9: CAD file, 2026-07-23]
hardware/3D/modelovane/drzak_horni/drzak - Part 4.step
192.5 x 133.5 x 10.0 mm

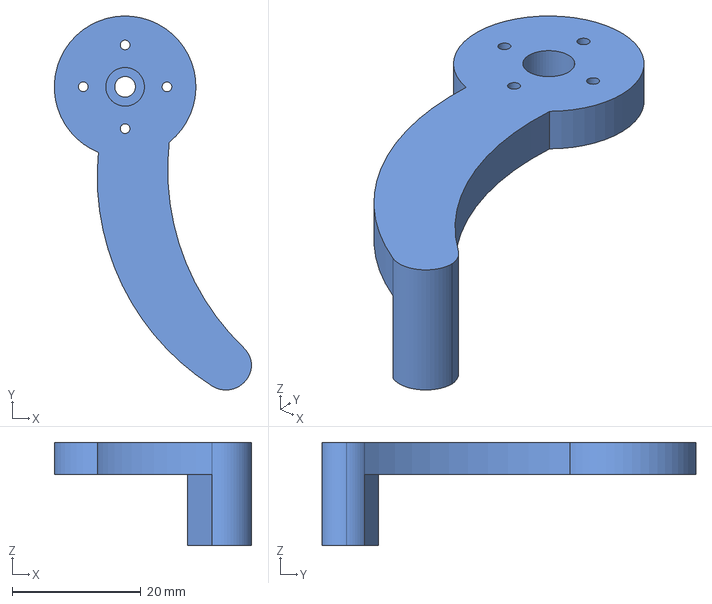
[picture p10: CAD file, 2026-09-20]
hardware/3D/modelovane/klepeto_ch_s.step
30.6 x 58.1 x 16.0 mm

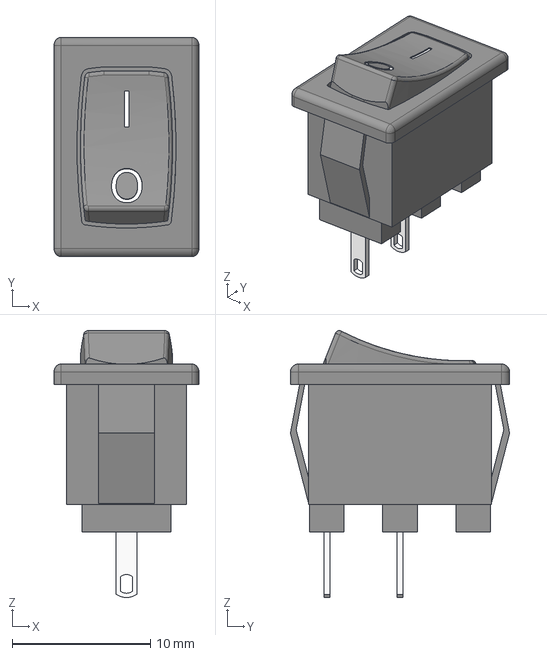
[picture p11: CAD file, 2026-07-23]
hardware/3D/rocker switch KCD11 v1.step
10.5 x 15.8 x 19.3 mm

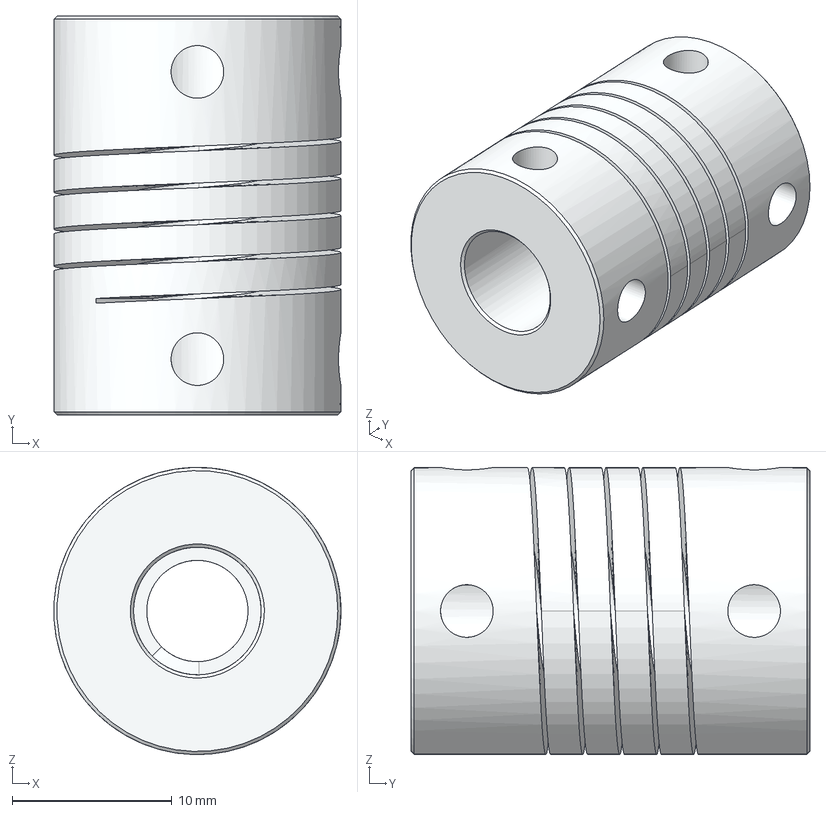
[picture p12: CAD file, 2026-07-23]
hardware/3D/D19L25.step
18.0 x 25.0 x 18.0 mm

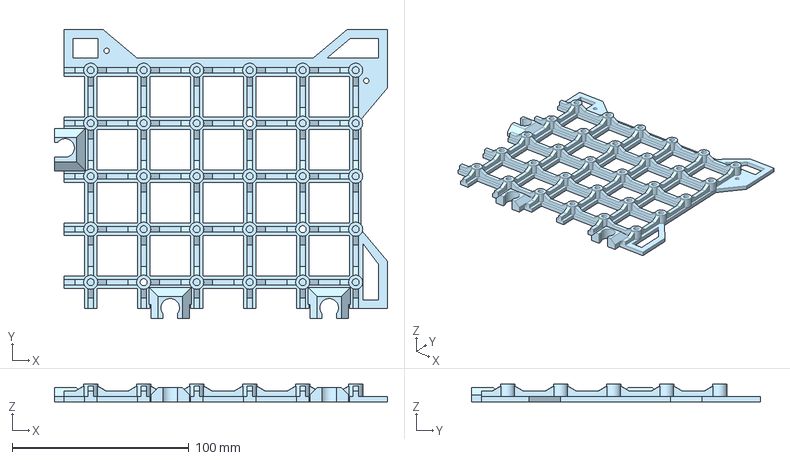
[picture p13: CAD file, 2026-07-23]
hardware/3D/modelovane/drzak_dolni/drzak_dolni_3.step
188.5 x 163.5 x 10.0 mm

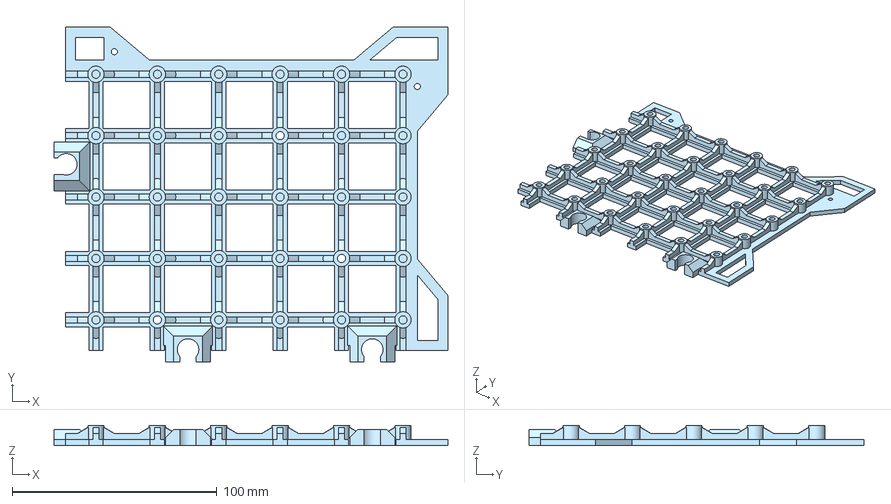
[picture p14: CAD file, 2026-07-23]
hardware/3D/modelovane/drzak_horni/drzak - Part 3.step
192.5 x 163.5 x 10.0 mm

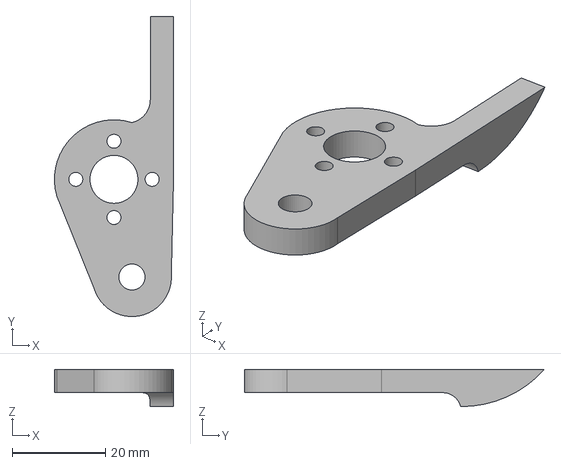
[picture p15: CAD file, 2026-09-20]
hardware/3D/modelovane/nuz.step
25.6 x 64.5 x 8.00 mm

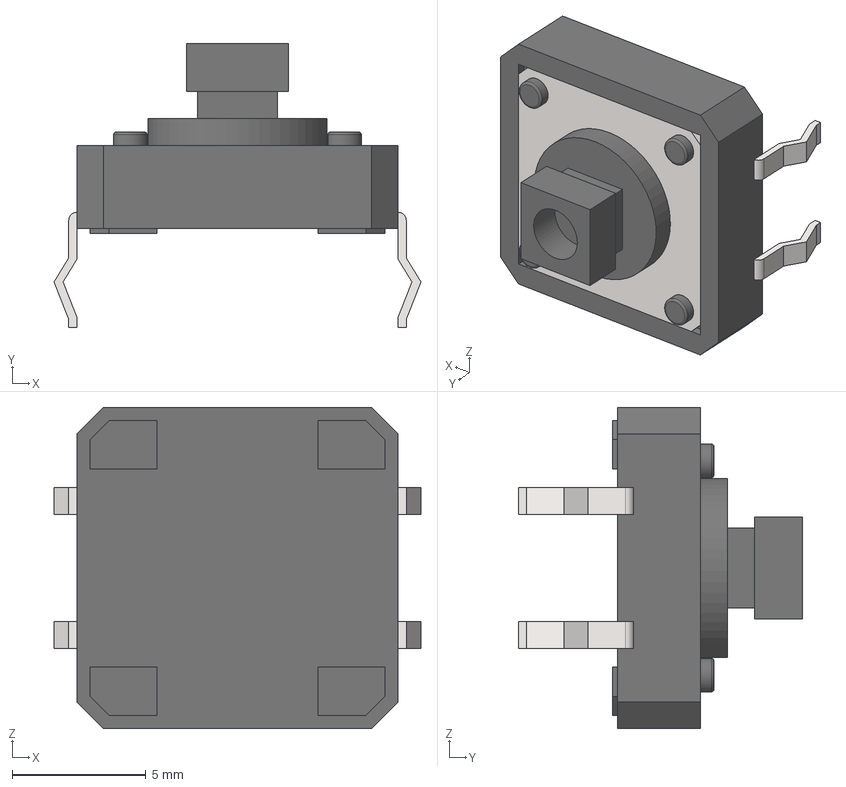
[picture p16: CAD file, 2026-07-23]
hardware/3D/12mm Push Button.step
13.7 x 10.6 x 12.0 mm

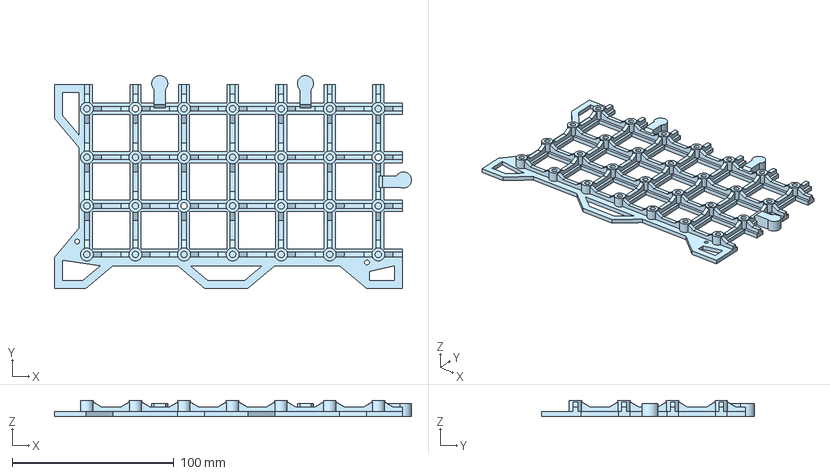
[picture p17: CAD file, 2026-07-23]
hardware/3D/modelovane/drzak_dolni/drzak _dolni_2.step
220.5 x 131.5 x 10.0 mm

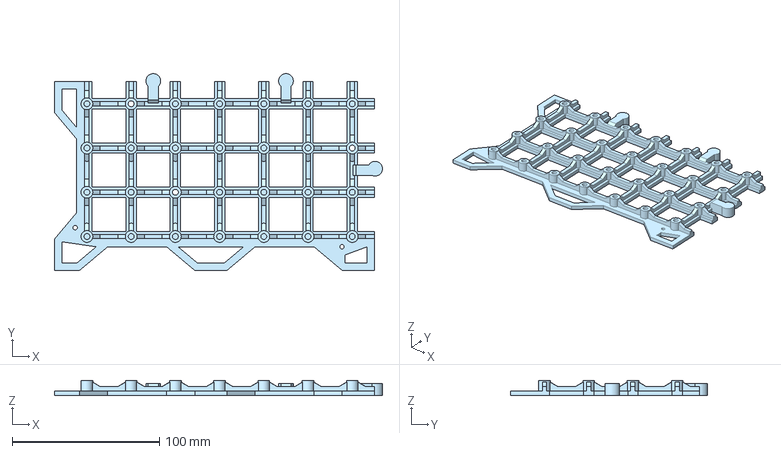
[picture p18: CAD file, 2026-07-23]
hardware/3D/modelovane/drzak_horni/drzak - Part 2.step
222.5 x 133.5 x 10.0 mm

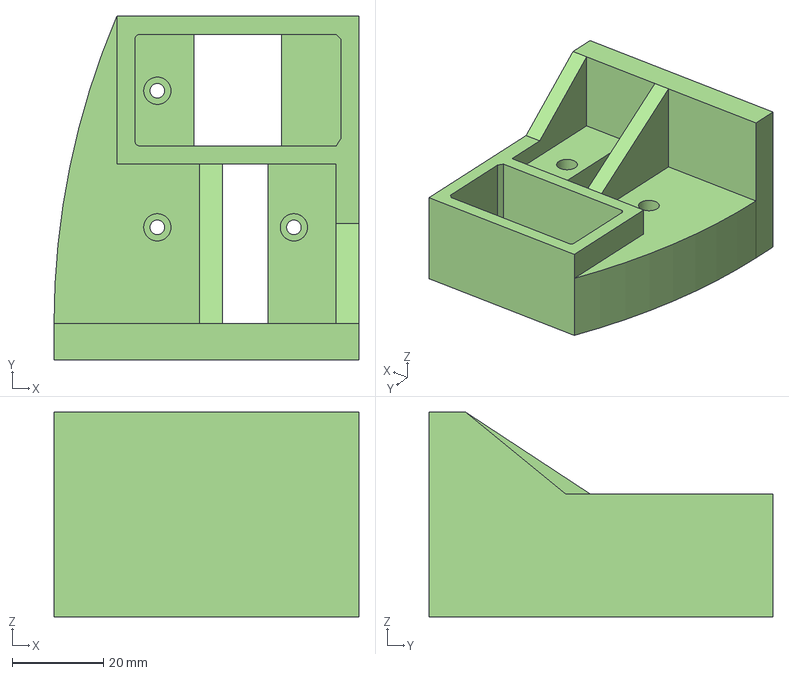
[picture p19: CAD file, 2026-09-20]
hardware/3D/modelovane/smart_s_drzak.step
67.0 x 75.5 x 45.0 mm

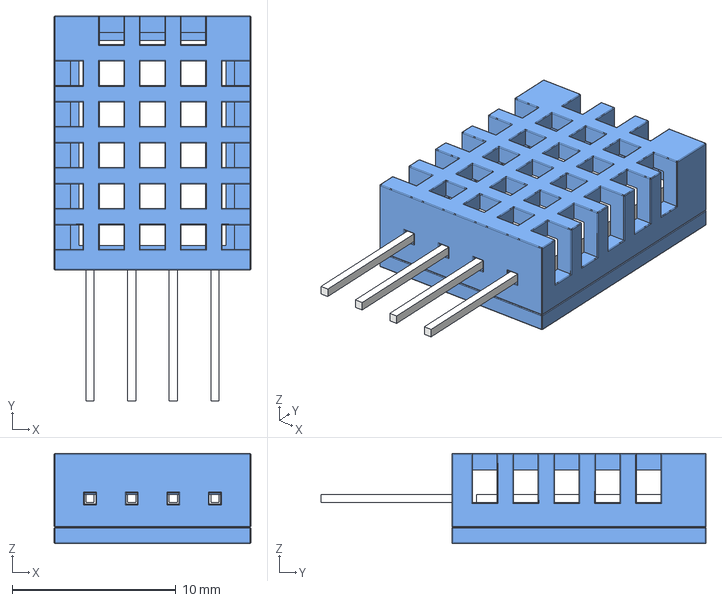
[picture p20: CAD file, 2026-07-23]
hardware/3D/DHT11.step
12.0 x 23.5 x 5.50 mm

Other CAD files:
hardware/3D/modelovane/drzak_dolni/drzak_dolni_4.step
hardware/3D/modelovane/drzak_horni/drzak - Part 1.step
hardware/3D/modelovane/drzak_loziska.step
hardware/3D/LM2596S_Y000022.step
hardware/3D/2.8- Display.step
hardware/3D/28BYJ-48.step
hardware/3D/8mm Pillow Block (KP08).step
hardware/3D/Buzzer Module - FC-07 - PCB.step
hardware/3D/DSN-VC288.step
hardware/3D/GY-VL53LDK.step
hardware/3D/HC-SR04.step
hardware/3D/HW-040.step
hardware/3D/Joystick Module.step
hardware/3D/LCD 1602.step
hardware/3D/LSM6DS3(1).step
hardware/3D/LSM6DS3.step
hardware/3D/LX-16A.step
hardware/3D/Led 5mm - white.step
hardware/3D/MG995.step
hardware/3D/MODULO SENSOR OPTICO MH.step
hardware/3D/MOS Module.step
hardware/3D/MTS-102-switch.step
hardware/3D/OLED 0.96.step
hardware/3D/Sensor, IR, Arduino Type, Flying Fish MH-B.step
hardware/3D/T8 Brass nut.step
hardware/3D/T8 LEAD SCREW.step
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

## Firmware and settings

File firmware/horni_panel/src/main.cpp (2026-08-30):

#include <Arduino.h>
#include "SystemState.h"
#include "HardwareSetup.h"
#include "GraphicsManager.h"
#include "SensorManager.h"
#include "UartProtocol.h"
#include "esp_sleep.h"
#include "hry/snake.h"
#include "hry/flappy_bird.h"
#include "hry/game_2048.h"
#include "wifi/WebManager.h"

// ---------------------------------------------------------
// Fyzická instance Globálního Stavu (paměť)
// ---------------------------------------------------------
SystemState globalState;
SnakeGame snake;
FlappyGame flappy;
Game2048 g2048;
WebManager webManager;

// ---------------------------------------------------------
// 1. Task: Wi-Fi a WebServer (Poběží na Core 0)
// ---------------------------------------------------------
void Task_WiFi_Web(void *pvParameters) {
    Serial.print("Task_WiFi_Web bezi na uvazku (Core): ");
    Serial.println(xPortGetCoreID());

    // Spuštění SoftAP, Captive Portalu, WebServeru a WebSocketu
    webManager.begin(&globalState);

    for (;;) {
        webManager.update();
        vTaskDelay(pdMS_TO_TICKS(15));
    }
}

// ---------------------------------------------------------
// 2A. Task: Demo Autopilot (Simulátor pro testování displeje)
// ---------------------------------------------------------
void Task_UART_Simulator(void *pvParameters) {
    Serial.print("Demo Autopilot bezi na uvazku (Core): ");
    Serial.println(xPortGetCoreID());

    int timeInMode = 0;
    AppMode lastMode = globalState.getMode();

    for (;;) {
        vTaskDelay(pdMS_TO_TICKS(50)); 
        
        AppMode current = globalState.getMode();
        if (current != lastMode) {
            timeInMode = 0; // Uživatel ručně změnil mód (z webu nebo tlačítkem) -> resetujeme časovač!
            lastMode = current;
        } else {
            timeInMode += 50;
        }
        
        float t = millis() / 1000.0f;

        // ---------------------------------------------------------
        // 1. GENERÁTOR NÁHODNÝCH DAT (Změna hodnot cca 3x za 10 sekund)
        // ---------------------------------------------------------
        if (timeInMode % 3300 < 50) {
            // A) Gyroskop: náhodné stabilní úhly v reálném rozsahu (např. -34.2°, +13.9°, +24.8°)
            float simRoll  = (float)random(-450, 451) / 10.0f;
            float simPitch = (float)random(-300, 301) / 10.0f;
            float simYaw   = (float)random(-600, 601) / 10.0f;

            float radR = simRoll * (PI / 180.0f);
            float radP = simPitch * (PI / 180.0f);
            float ax = -sin(radP);
            float ay = sin(radR);
            float az = cos(radR);
            globalState.updateIMU(ax, ay, az, simPitch, simRoll, simYaw);

            // B) Barevný senzor: náhodné čisté barvy
            uint8_t r = random(20, 256);
            uint8_t g = random(20, 256);
            uint8_t b = random(20, 256);
            globalState.updateColor(r, g, b, 200);

            // C) Hlavní menu: náhodné polohy ovladačů
            int simPot = random(200, 4000);
            globalState.updatePotentiometer(simPot);

            int simJoyX = random(200, 4000);
            int simJoyY = random(200, 4000);
            globalState.updateJoystick(simJoyX, simJoyY, false);

            int simPhoto1 = random(300, 3900);
            int simPhoto2 = random(300, 3900);
            globalState.updatePhotoresistors(simPhoto1, simPhoto2);

            bool b0 = (random(0, 2) == 1);
            bool b1 = (random(0, 2) == 1);
            bool b2 = (random(0, 2) == 1);
            bool b3 = (random(0, 2) == 1);
            bool b4 = (random(0, 2) == 1);
            globalState.updateDownButtons(b0, b1, b2, b3, b4);

            float sim_ultrasonic = (float)random(100, 2000) / 10.0f; // 10.0 až 200.0 cm (100 až 2000 mm)
            float sim_ir         = (float)random(30, 300) / 10.0f;   // 3.0 až 30.0 cm (30 až 300 mm)
            uint16_t sim_laser   = (uint16_t)random(80, 1300);       // 80 až 1300 mm

            globalState.updateUltrasonicDistance(sim_ultrasonic);
            globalState.updateIRDistance(sim_ir);
            globalState.updateLaserDistance(sim_laser);

            int p = random(0, 3);
            globalState.updateLeds(p == 0, p == 1, p == 2);
        }

        // ---------------------------------------------------------
        // 2. PŘEPÍNÁNÍ MEZI MÓDY (Wi-Fi módy 40s, ostatní 10s)
        // ---------------------------------------------------------
        int requiredDuration = (current == MODE_WIFI_SPOJENI || current == MODE_WIFI_DETECTION) ? 40000 : 10000;
        if (timeInMode >= requiredDuration) {
            timeInMode = 0;
            AppMode nextMode = MODE_MAIN_MENU;
            
            if (current == MODE_MAIN_MENU) {
                nextMode = MODE_GYRO; // GYROSKOP (10s)
            } else if (current == MODE_GYRO) {
                nextMode = MODE_BAREVNY; // BAREVNÝ SENZOR (10s)
            } else if (current == MODE_BAREVNY) {
                nextMode = MODE_VZDALENOST; // VZDÁLENOST (10s)
            } else if (current == MODE_VZDALENOST) {
                nextMode = MODE_WIFI_SPOJENI; // WIFI SPOJENÍ & QR KÓD (40s)
            } else if (current == MODE_WIFI_SPOJENI) {
                nextMode = MODE_WIFI_DETECTION; // WIFI CSI DETEKCE POHYBU (40s)
            } else {
                nextMode = MODE_MAIN_MENU; // Zpět do HLAVNÍHO MENU (10s)
            }

            Serial.printf("[DEMO 6-MODU] Prepinam na mod: %d (doba: %d s)\n", (int)nextMode, (nextMode == MODE_WIFI_SPOJENI || nextMode == MODE_WIFI_DETECTION) ? 40 : 10);
            globalState.setMode(nextMode);
        }
    }
}


void Task_UART(void *pvParameters) {
    unsigned long lastSendTime = 0;
    
    // Vyrovnávací paměti pro pakety
    TopToBottomPacket outPacket;
    BottomToTopPacket inPacket;

    for (;;) {
        unsigned long now = millis();

        // -------------------------------------------------------------
        // 1. ODESÍLÁNÍ (HORNÍ -> DOLNÍ PANEL)
        // -------------------------------------------------------------
        bool hasChanged = globalState.popBottomNeedsTx();
        bool heartbeatTimeout = (now - lastSendTime >= 200);

        // Pošli pokud: Nastala změna NEBO vypršelo 200 ms od posledního odeslání
        if (hasChanged || heartbeatTimeout) {
            lastSendTime = now;

            // A) Zkopírujeme si aktuální stav ze SystemState
            SensorData data = globalState.getSensorData();

            // B) Naplníme odchozí paket
            outPacket.startByte = UART_FRAME_START_TOP_TO_BOTTOM; // 0xAA
            outPacket.currentMode = (uint8_t)globalState.getMode();
            outPacket.overrideAutonomy = false; // Nebo true podle potřeby
            
            outPacket.targetSmartServoAngle = data.smartServoAngle;
            outPacket.targetServoAngle = data.servoAngle;
            outPacket.targetContinuousServo = data.continuousServoSpeed;
            outPacket.targetMotorSpeed = data.motorSpeed;

            for (int i = 0; i < 8; i++) {
                outPacket.ledStrip[i] = data.ledStripBottom[i];
            }
            outPacket.ledBrightness = data.ledStripBottomBrightness;

            strncpy(outPacket.oledLine1, data.bottomOledLine1, 16);
            outPacket.oledLine1[16] = '\0';
            strncpy(outPacket.oledLine2, data.bottomOledLine2, 16);
            outPacket.oledLine2[16] = '\0';

            outPacket.endByte = UART_FRAME_END; // 0xFE

            // C) Spočítáme kontrolní součet ze všech datových bajtů před checksumem
            outPacket.checksum = calculateChecksum(
                (const uint8_t*)&outPacket, 
                sizeof(TopToBottomPacket) - 2 // Odečteme checksum a endByte
            );

            // D) Odešleme celý binární blok najednou
            SerialESP.write((const uint8_t*)&outPacket, sizeof(TopToBottomPacket));
        }

        // -------------------------------------------------------------
        // 2. PŘÍJEM (DOLNÍ -> HORNÍ PANEL)
        // -------------------------------------------------------------
        
        while (SerialESP.available() >= sizeof(BottomToTopPacket)) {
            
            // 2. KONTROLA ZAČÁTKU (Synchronizace):
            // Funkce peek() se jen "podívá" na první bajt v bufferu, ale nesmaže ho
            if (SerialESP.peek() != UART_FRAME_START_BOTTOM_TO_TOP) { // Není to 0x55?
                SerialESP.read(); // Zahodíme 1 vadný bajt a zkusíme to v dalším kole znova
                continue;
            }
            // 3. PŘEČTENÍ CELÉHO PAKETU NARÁZ
            // readBytes bleskově nasype všechny bajty přímo do naší struktury v paměti!
            SerialESP.readBytes((uint8_t*)&inPacket, sizeof(BottomToTopPacket));
            // 4. KONTROLA KONCE A KONTROLNÍHO SOUČTU
            uint8_t calculatedCRC = calculateChecksum(
                (const uint8_t*)&inPacket, 
                sizeof(BottomToTopPacket) - 2
            );
            // Ověříme, že sedí koncový bajt (0xFE) i náš XOR checksum
            if (inPacket.endByte == UART_FRAME_END && inPacket.checksum == calculatedCRC) {
                
                // 5. DATA JSOU 100% V POŘÁDKU -> ZAPÍŠEME JE DO SYSTEMSTATE
                globalState.updateJoystick(inPacket.joyX, inPacket.joyY, inPacket.joyBtn);
                globalState.updateDownButtons(
                    inPacket.btnDown[0], inPacket.btnDown[1], 
                    inPacket.btnDown[2], inPacket.btnDown[3], inPacket.btnDown[4]
                );
                globalState.updateEncoder(inPacket.encoderPos, inPacket.encoderDelta, inPacket.encoderBtn);
                globalState.updatePotentiometer(inPacket.potentiometer);
                globalState.updateSwitches(inPacket.switch1, inPacket.switch2);
                
                // Zpětná vazba z akčních členů
                globalState.updateSmartServo(inPacket.currentSmartServoAngle);
                globalState.updateServo(inPacket.currentServoAngle);
                globalState.updateMotor(inPacket.currentMotorSpeed);
                globalState.updateContinuousServo(inPacket.currentContinuousServo);
                
            } else {
                // Pokud nesedí checksum (rušení na drátě), paket jednoduše ignorujeme
                Serial.println("[UART] Chyba kontrolniho souctu! Paket zahozen.");
            }
        }

        // -------------------------------------------------------------
        // Krátká neblokující prodleva (smyčka běží každých 10 ms)
        vTaskDelay(pdMS_TO_TICKS(10));
    }
}

// ---------------------------------------------------------
// 3. Task: Senzory a vstupy (Poběží na Core 1)
// ---------------------------------------------------------
void Task_Sensors(void *pvParameters) {
    Serial.print("Task_Sensors bezi na uvazku (Core): ");
    Serial.println(xPortGetCoreID());

    for (;;) {
        AppMode currentMode = globalState.getMode();

        // Kontrola otočení rotačního enkodéru pro změnu módu
        globalState.checkModeChange();

        switch (currentMode) {

            case MODE_SLEEP: {
                vTaskDelay(pdMS_TO_TICKS(100));
                break;
            }
            
            case MODE_MAIN_MENU: {
                sensorManager.readDHT();
                sensorManager.readUltrasonic();
                sensorManager.readVL53L0X();
                sensorManager.readIRDistance();
                sensorManager.readPhotoresistors();
                sensorManager.readTopButton();
                sensorManager.readColorSensor();

                SensorData data = globalState.getSensorData();

                //teplo a vlhkost na 1602
                sensorManager.writeLCD1602("Temp: " + String(data.temperature, 1) + "C", 
                                 "Hum: " + String(data.humidity, 1) + "%");

                if(data.led_ult){
                    sensorManager.set7Segment(data.ultrasonicDistanceCm);
                    sensorManager.setLeds(true, false, false);
                }else if(data.led_ir){
                    sensorManager.set7Segment(data.irDistanceCm);
                    sensorManager.setLeds(false, true, false);
                }else if(data.led_laser){
                    sensorManager.set7Segment(data.laserDistanceMm);
                    sensorManager.setLeds(false, false, true);
                }else{
                    sensorManager.set7Segment(-1); // Zhasneme 7-segmentový displej
                    sensorManager.setLeds(false, false, false);
                }

                //horni led pasek podle barevnyho

                sensorManager.setLedStripColor(
                    (data.colorR << 16) | (data.colorG << 8) | data.colorB, 
                    data.ledStripTopBrightness
                );

                







                break;
            }

            case MODE_GYRO:
            case MODE_GAME_SNAKE:
            case MODE_GAME_FLAPPY:
            case MODE_2048:
            case MODE_VZDALENOST:
            case MODE_WIFI_SPOJENI:
            case MODE_WIFI_DETECTION:
            case MODE_SERVA:
            case MODE_MOTOR:
            case MODE_BAREVNY: {
                sensorManager.readAllSensors();
                break;
            }
        }

        vTaskDelay(pdMS_TO_TICKS(50)); // Prodleva v simulátoru
    }
}

// ---------------------------------------------------------
// 4. Task: Displej a State Machine (Poběží na Core 1)
// ---------------------------------------------------------
void Task_Display_UI(void *pvParameters) {
    Serial.print("Task_Display_UI bezi na uvazku (Core): ");
    Serial.println(xPortGetCoreID());
    unsigned long casPoslednihoKroku = 0;
    byte delay = 50; // Defaultní zpoždění mezi překresleními (20 fps)

    // Inicializace gfx je hotová v HardwareSetup. Nyní můžeme kreslit.
    static bool lastBtnDown[5] = {false, false, false, false, false};
    static bool lastBtnTop = false;
    static int32_t lastEncoderPos = 0;

    for (;;) {
        // 1. Zjistíme, v jakém stavu se kufr zrovna nachází
        AppMode currentMode = globalState.getMode();

        // ---------------------------------------------------------
        // OBSLUHA FYZICKÝCH / VIRTUÁLNÍCH TLAČÍTEK A ENKODÉRU PRO PŘEPÍNÁNÍ MÓDŮ
        // ---------------------------------------------------------
        SensorData currentSensors = globalState.getSensorData();

        // A) Enkodér pro procházení módů
        int32_t encDiff = currentSensors.encoderPos - lastEncoderPos;
        if (abs(encDiff) >= 4) {
            int step = (encDiff > 0) ? 1 : -1;
            int nextM = ((int)currentMode + step + 12) % 12;
            globalState.setMode((AppMode)nextM);
            currentMode = (AppMode)nextM;
            lastEncoderPos = currentSensors.encoderPos;
        }

        // Horní fyzické tlačítko: Návrat do Menu nebo info
        if (currentSensors.btnTop && !lastBtnTop) {
            if (currentMode != MODE_MAIN_MENU) {
                globalState.setMode(MODE_MAIN_MENU);
                currentMode = MODE_MAIN_MENU;
            } else {
                globalState.toggleInfo();
            }
        }
        lastBtnTop = currentSensors.btnTop;
        
        // 2. Potřebujeme kompletně překreslit obrazovku? 
        // (Vlajka je true jen těsně po přepnutí stavu nebo stisku tlačítka)
        bool needsFullRedraw = globalState.popUiNeedsUpdate();

        //vykreslujeme info?
        bool infoActive = globalState.isInfoActive();

        // 3. Vykreslujeme podle módu
        switch (currentMode) {
            
            // =======================================================
            case MODE_SLEEP: {
                Serial.println("[SYSTEM] Prechazim do rezimu Light Sleep...");


                // 1. Zhasneme displej a vypneme jeho podsvícení
                gfx.clearScreen(ST77XX_BLACK);
                #ifdef PIN_TFT_LED
                    digitalWrite(PIN_TFT_LED, LOW);
                #endif

                // 2. Vypneme 3x LED diody na horním panelu
                #ifdef ENABLE_LEDS
                    sensorManager.setLeds(false, false, false);
                #endif

                // 3. Zhasneme 8-LED WS2812B pásek
                #ifdef ENABLE_WS2812B
                    uint32_t offLeds[8] = {0};
                    sensorManager.setLedStrip(offLeds, 0);
                #endif

                // 4. Vypneme bzučák
                #ifdef ENABLE_BUZZER
                    sensorManager.setBuzzer(false, 0);
                #endif

                // 5. Zhasneme 7-segmentový displej
                #ifdef ENABLE_74HC595
                    sensorManager.set7Segment(-1);
                #endif

                // 6. Zhasneme I2C LCD 1602 displej a jeho podsvícení
                #ifdef ENABLE_LCD1602
                    sensorManager.setLCDBacklight(false);
                #endif

                // 7. Vyprázdníme sériové buffery před uspáním
                Serial.flush();
                #ifdef ENABLE_UART_ESP
                    SerialESP.flush();
                #endif

                // 8. Nastavení všech 3 hardwarových zdrojů probuzení:
                // A) Horní tlačítko 1 (stisk spojí na GND = LOW)
                #ifdef PIN_BTN1
                    gpio_wakeup_enable((gpio_num_t)PIN_BTN1, GPIO_INTR_LOW_LEVEL);
                #endif

                // B) Akcelerometr LSM6DS3 (INT1 na GPIO 45 – impuls HIGH při otřesu/klepnutí)
                #ifdef PIN_IMU_INT
                    gpio_wakeup_enable((gpio_num_t)PIN_IMU_INT, GPIO_INTR_HIGH_LEVEL);
                #endif

                // Povolení GPIO probuzení (tlačítko + akcelerometr)
                esp_sleep_enable_gpio_wakeup();

                // C) UART z dolního panelu (UART1 – jakákoliv aktivita zdola)
                #ifdef ENABLE_UART_ESP
                    esp_sleep_enable_uart_wakeup(1);
                #endif

                // 9. VSTUP DO SKUTEČNÉHO LEHKÉHO SPÁNKU
                // (Procesor zastaví hodiny, minimální odběr proudu, RAM zůstává plně zachována)
                esp_light_sleep_start();

                // ===================================================
                // 10. PROBUZENÍ! (Kód pokračuje okamžitě zde)
                // ===================================================
                #ifdef PIN_TFT_LED
                    digitalWrite(PIN_TFT_LED, HIGH); // Znovu rozsvítíme podsvícení displeje
                #endif

                #ifdef ENABLE_LCD1602
                    sensorManager.setLCDBacklight(true); // Znovu rozsvítíme LCD 1602
                #endif

                esp_sleep_wakeup_cause_t duvod = esp_sleep_get_wakeup_cause();
                Serial.printf("[SYSTEM] Probudil jsem se z Light Sleep! (Duvod kod: %d) -> ", (int)duvod);
                if (duvod == ESP_SLEEP_WAKEUP_GPIO) {
                    Serial.println("PROBUZENO TLACITKEM NEBO OTRESEM (GPIO)");
                } else if (duvod == ESP_SLEEP_WAKEUP_UART) {
                    Serial.println("PROBUZENO Z DOLNIHO PANELU (UART)");
                } else {
                    Serial.printf("PROBUZENO JINYM ZDROJEM: %d\n", (int)duvod);
                }

                // Krátká prodleva na stabilizaci po probuzení
                vTaskDelay(pdMS_TO_TICKS(100));

                // Vrátíme se do předchozího módu (pokud byl předchozí mód na konci demo cyklu, začneme od Menu)
                AppMode returnMode = globalState.getLastMode();
                if (returnMode == MODE_SLEEP || returnMode == MODE_BAREVNY) {
                    returnMode = MODE_MAIN_MENU;
                }
                globalState.setMode(returnMode);
                break;
            }

            // =======================================================
            case MODE_MAIN_MENU: {
                delay = 50; // Defaultní zpoždění mezi překresleními (20 fps)
                bool isInfo = globalState.isInfoActive();
                isInfo = true;

                if (isInfo) {
                    if (needsFullRedraw) {
                        // INFO OVERLAY pro Hlavní menu
                        gfx.clearScreen(ST77XX_BLACK);
                        gfx.drawRoundRect(10, 10, 300, 220, 8, ST77XX_YELLOW);
                        gfx.drawTextPartial(30, 25, "INFO: HLAVNI MENU", ST77XX_YELLOW, ST77XX_BLACK, 2);
                        
                        gfx.drawTextPartial(25, 60, "- Enkoder: Rotace meni mody", ST77XX_WHITE, ST77XX_BLACK, 1);
                        gfx.drawTextPartial(25, 80, "- Joy stisk: Rychly vyber modu", ST77XX_WHITE, ST77XX_BLACK, 1);
                        gfx.drawTextPartial(25, 100, "- Potenciometr: Uhel serva", ST77XX_WHITE, ST77XX_BLACK, 1);
                        gfx.drawTextPartial(25, 120, "- Joystick Y: Kontinualni servo", ST77XX_WHITE, ST77XX_BLACK, 1);
                        gfx.drawTextPartial(25, 140, "- Dolni tlacitka: Volba pro 7-seg", ST77XX_WHITE, ST77XX_BLACK, 1);
                        gfx.drawTextPartial(25, 160, "- Horni tlacitko (1s): Rezim spanku", ST77XX_WHITE, ST77XX_BLACK, 1);
                        
                        gfx.drawTextPartial(40, 195, "[Stiskni horni tlacitko pro zpet]", ST77XX_GREEN, ST77XX_BLACK, 1);
                    }
                }
                else {
                    SensorData data = globalState.getSensorData();

                    // Statické proměnné pro detekci změn (překreslujeme JEN při reálné změně)
                    static int lastPhotoL = -1;
                    static int lastPhotoR = -1;
                    static int lastPot = -1;
                    static int lastJoyX = -1;
                    static int lastJoyY = -1;
                    static uint16_t lastColor = 0xFFFF;
                    static int lastStations = -1;
                    static uint8_t lastButtons = 0xFF;
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
void loop() {
    vTaskDelay(pdMS_TO_TICKS(1000));
}

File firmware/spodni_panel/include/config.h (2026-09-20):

/**
 * @file config.h
 * @brief Hlavní konfigurační soubor pro Spodní panel (ESP-Demo-Box - Maturitní projekt)
 *
 * Hardwarová platforma: ESP32-WROOM-32 (38 pinů)
 * Framework:            Arduino / PlatformIO
 */

#pragma once

// =============================================================================
//  MODULÁRNÍ PŘEPÍNAČE (Odkomentuj pro aktivaci daného modulu)
// =============================================================================

#define ENABLE_OLED_SSD1306   // 0.96" OLED displej (I2C 0x3C, Adafruit_SSD1306)
#define ENABLE_UART_TOP       // UART komunikace s Horním panelem (Serial2 / UART1)
#define ENABLE_JOYSTICK       // Analogový joystick (X, Y) a tlačítko (SW)
#define ENABLE_POTENTIOMETER  // Analogový potenciometr
#define ENABLE_ENCODER        // Rotační enkodér (CLK, DT)
#define ENABLE_BUTTONS        // Digitální tlačítka (1 až 5 / směrový kříž)
#define ENABLE_SWITCHES       // Páčkové přepínače (1 a 2)
#define ENABLE_SERVO_CLASSIC  // Klasické PWM servo (0-180°)
#define ENABLE_SERVO_CONT     // Kontinuální PWM servo (360°)
#define ENABLE_SMART_SERVO    // Jednodrátové Smart Servo LX-16A (UART)
#define ENABLE_MOTOR_CTRL     // Řízení motoru (PWM / Výkonový MOSFET)
#define ENABLE_LED_STRIP      // Adresovatelný LED pásek WS2812B
//#define ENABLE_I2C          // Samostatné skenování I2C sběrnice

// Kompatibilita pro novější názvy modulů
#define ENABLE_SERVO_SMART    ENABLE_SMART_SERVO
#define ENABLE_MOTOR_MOSFET   ENABLE_MOTOR_CTRL

// =============================================================================
//  SBĚRNICE A KOMUNIKACE
// =============================================================================

// I2C sběrnice pro OLED displej SSD1306
#define PIN_I2C_SDA         21
#define PIN_I2C_SCL         22

// UART linka pro komunikaci s horním panelem (křížem do horního ESP)
#define PIN_UART_TOP_TX     17   // Výstup TX -> vede do RX horního panelu
#define PIN_UART_TOP_RX     16   // Vstup RX  <- vede z TX horního panelu
#define PIN_SMART_SERVO     14   // Jednodrátový UART pro LX-16A Smart Servo
#define PIN_SERVO_SMA       PIN_SMART_SERVO

// =============================================================================
//  OLED DISPLEJ 0.96" (I2C SSD1306)
// =============================================================================
#define OLED_SCREEN_WIDTH  128
#define OLED_SCREEN_HEIGHT  64
#define OLED_RESET          -1   // Reset sdílený s procesorem
#define OLED_SCREEN_ADDRESS 0x3C // I2C adresa displeje
#define OLED_SCREEN_ADDR    OLED_SCREEN_ADDRESS

// =============================================================================
//  ANALOGOVÉ VSTUPY (ADC1 převodník – stabilní i při zapnuté Wi-Fi)
// =============================================================================
// V kódu v setup(): pinMode(PIN_..., INPUT); čtení přes analogRead(PIN_...)
#define PIN_JOY_X           36   // Osa X joysticku (VP / Sensor_VP, 0 až 3.3 V)
#define PIN_JOY_Y           39   // Osa Y joysticku (VN / Sensor_VN, 0 až 3.3 V)
#define PIN_POTENTIOMETER   34   // Otočný potenciometr (0 až 3.3 V)

// Aliasy pro alternativní značení os
#define PIN_JOY_VRX         PIN_JOY_X
#define PIN_JOY_VRY         PIN_JOY_Y

// =============================================================================
//  DIGITÁLNÍ VSTUPY – TLAČÍTKA A ENKODÉR (Active LOW – Spínají proti GND)
// =============================================================================
// DŮLEŽITÉ: Všechny tyto piny vyžadují aktivaci vnitřního pull-upu:
// V kódu v setup(): pinMode(PIN_..., INPUT_PULLUP);
// Stisknuto = LOW (0 V) | Uvolněno = HIGH (3.3 V)

#define PIN_JOY_SW           2   // Tlačítko joysticku (spíná GND -> bezpečný boot!)
#define PIN_BTN_1           12   // Tlačítko 1 / SW1 (Vlevo) - spíná GND (bezpečné pro Flash 3.3V)
#define PIN_BTN_2           23   // Tlačítko 2 / SW2 (Střed / OK) - spíná GND
#define PIN_BTN_3            5   // Tlačítko 3 / SW3 (Vpravo) - spíná GND
#define PIN_BTN_4           15   // Tlačítko 4 / SW4 (Nahoru) - spíná GND
#define PIN_BTN_5           26   // Tlačítko 5 / SW5 (Dolů) - spíná GND

#define PIN_ENC_CLK         32   // Rotační enkodér CLK -> INPUT_PULLUP
#define PIN_ENC_DT           4   // Rotační enkodér DT  -> INPUT_PULLUP
// Poznámka: Tlačítko enkodéru (SW) zůstalo nezapojené (NC)

// Aliasy pro označení SW1 až SW5
#define PIN_BTN_SW1         PIN_BTN_1
#define PIN_BTN_SW2         PIN_BTN_2
#define PIN_BTN_SW3         PIN_BTN_3
#define PIN_BTN_SW4         PIN_BTN_4
#define PIN_BTN_SW5         PIN_BTN_5

// =============================================================================
//  DIGITÁLNÍ VSTUPY – PÁČKOVÉ PŘEPÍNAČE (Active HIGH)
// =============================================================================
// DŮLEŽITÉ: Tyto piny mají na desce externí 10k pull-down rezistory k zemi.
// V kódu v setup(): pinMode(PIN_..., INPUT); (NEPOUŽÍVAT INPUT_PULLUP!)
// Sepnuto (ON + svítí LED) = HIGH (3.3 V) | Vypnuto (OFF) = LOW (0 V)
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

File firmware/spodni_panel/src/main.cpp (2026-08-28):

#include <Arduino.h>
#include "config.h"
#include "SystemState.h"
#include "HardwareSetup.h"
#include "SensorManager.h"
#include "UartProtocol.h"

// ---------------------------------------------------------
// Fyzická instance Globálního Stavu spodního panelu
// ---------------------------------------------------------
SystemState globalState;

// ---------------------------------------------------------
// 1. Task: UART Komunikace s Horním panelem (Core 0)
// ---------------------------------------------------------
void Task_UART(void *pvParameters) {
    Serial.print("[TASK] Task_UART bezi na jadre: ");
    Serial.println(xPortGetCoreID());

#ifdef ENABLE_UART_TOP
    unsigned long lastSendTime = 0;
    TopToBottomPacket inPacket;
    BottomToTopPacket outPacket;

    for (;;) {
        unsigned long now = millis();

        // ---------------------------------------------------------
        // 1. PŘÍJEM PŘÍKAZŮ Z HORNÍHO PANELU (TOP -> BOTTOM)
        // ---------------------------------------------------------
        while (SerialTop.available() >= sizeof(TopToBottomPacket)) {
            // Kontrola startovního bajtu 0xAA
            if (SerialTop.peek() != UART_FRAME_START_TOP_TO_BOTTOM) {
                SerialTop.read(); // Zahodíme poškozený bajt a hledáme začátek
                continue;
            }

            // Přečtení celého paketu
            SerialTop.readBytes((uint8_t*)&inPacket, sizeof(TopToBottomPacket));

            // Výpočet a ověření kontrolního součtu
            uint8_t calculatedCRC = calculateChecksum(
                (const uint8_t*)&inPacket,
                sizeof(TopToBottomPacket) - 2
            );

            if (inPacket.endByte == UART_FRAME_END && inPacket.checksum == calculatedCRC) {
                // Uložíme příkazy do SystemState pro aplikaci na hardware
                globalState.applyTopPacket(inPacket);
            } else {
                Serial.println("[UART] Chyba kontrolniho souctu prikazu! Paket zahozen.");
            }
        }

        // ---------------------------------------------------------
        // 2. ODESÍLÁNÍ TELEMETRIE DO HORNÍHO PANELU (BOTTOM -> TOP)
        // ---------------------------------------------------------
        bool hasChanged = globalState.popNeedsTx();
        bool heartbeatTimeout = (now - lastSendTime >= 50); // Heartbeat / stream perioda 50 ms

        if (hasChanged || heartbeatTimeout) {
            lastSendTime = now;

            BottomInputs in = globalState.getInputs();

            outPacket.startByte = UART_FRAME_START_BOTTOM_TO_TOP; // 0x55
            outPacket.joyX = in.joyX;
            outPacket.joyY = in.joyY;
            outPacket.joyBtn = in.joyBtn;

            for (int i = 0; i < 5; i++) {
                outPacket.btnDown[i] = in.btnDown[i];
            }

            outPacket.encoderPos = in.encoderPos;
            outPacket.encoderDelta = in.encoderDelta;
            outPacket.encoderBtn = in.encoderBtn;

            outPacket.potentiometer = in.potentiometer;
            
            BottomOutputs out = globalState.getOutputs();
            outPacket.currentSmartServoAngle = out.targetSmartServoAngle;
            outPacket.currentServoAngle = out.targetServoAngle;
            outPacket.currentContinuousServo = out.targetContinuousServo;
            outPacket.currentMotorSpeed = out.targetMotorSpeed;

            for (int i = 0; i < 8; i++) {
                outPacket.ledStrip[i] = out.ledStrip[i];
            }
            outPacket.ledBrightness = out.ledBrightness;

            outPacket.switch1 = in.switch1;
            outPacket.switch2 = in.switch2;
            outPacket.endByte = UART_FRAME_END; // 0xFE

            outPacket.checksum = calculateChecksum(
                (const uint8_t*)&outPacket,
                sizeof(BottomToTopPacket) - 2
            );

            SerialTop.write((const uint8_t*)&outPacket, sizeof(BottomToTopPacket));
        }

        vTaskDelay(pdMS_TO_TICKS(10));
    }
#else
    for (;;) {
        vTaskDelay(pdMS_TO_TICKS(1000));
    }
#endif
}
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

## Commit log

2026-06-27 Přidán příklad led_strip pro adresovatelný LED pásek a upraven platformio.ini
2026-06-27 Přidán příklad pro LED pásek s barevným senzorem TCS34725
2026-06-27 Zvýšení jasu LED pásku na max a vylepšení saturace a citlivosti barevného senzoru
2026-06-27 Přidán příklad lx16a_servo pro chytré servo
2026-06-27 Přidán příklad mg996r_servo pro kontinuální modelářské servo
2026-07-02 Update multi_view.cpp example to match current 3-screen switcher
2026-07-04 feat: integrate LSM6DS3 with Complementary Filter and add hardware examples
2026-07-23 Pridana kompletni funkcionalita horniho panelu, dokumentace a oprava pinoutu ESP32-S3
2026-07-23 Pridany 3D STEP modely a CAD podklady konstrukce
    [01_test.step, 12mm Push Button.step, 2.8- Display.step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]
2026-08-14 spodni_panel: Implementace obsluhy periferií a samostatných příkladů (joystick, potenciometr, enkodér, OLED, motor, LX-16A servo)
2026-08-15 feat: pridany hry Snake a Flappy Bird pro ESP32-S3 a dokumentace Double Bufferingu
2026-08-15 feat: Architektura horniho panelu (FreeRTOS, HardwareSetup) a dokumentace (Handshake, Edge Computing, Fail Log)
    [drzak_joy.step, nad_joy.step]
2026-08-16 Refaktor: Integrovat novy GraphicsManager, hry predelany na globalni platno, pripravena kostra pro hru 2048, fix syntaxe v main.cpp
    [GraphicsManager.cpp, HardwareSetup.cpp, SystemState.h]
2026-08-17 feat(firmware, docs): Dokončení ploché struktury SensorData, implementace SensorManageru, binární UART protokol a technická dokumentace
2026-08-18 jede klepnuti gyro
2026-08-18 feat(power): implementace Light Sleep s probuzenim pres IMU (GPIO 45), tlacitko a UART + dokumentace problemu 08
    [HardwareSetup.cpp, SystemState.h, main.cpp]
2026-08-28 rozvrzeni gyroskopu a barenyho.... a sam udelam vzdalenost....
2026-09-20 kicad schema a aktualizovane configy.h .... asi finalni rozvrzeni pinu
    [dolni.kicad_sch, drzak_9g.step, drzak_kontin_servo.step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]
2026-10-23 clean(spodni_panel): vypnuti UART zprav pro cisty vystup testu
2026-10-23 test(spodni_panel): vse funguje, pridana indikace switchu s LED a rizeni 180 servo pres pot
2026-10-23 fix(spodni_panel): oprava inicializace SmartServoBus podle funkcniho examplu (1 servo, 1s delay)
2026-10-24 oprava zaojeni ch serva.. ch.servo jedegit add .
2026-10-24 dole vse jede a je nastaveno....krome uart
2026-10-24 jede vse, krome fotorezistu leveho a gyro uhel nic moc
2026-10-25 vse jede... jdeme na uart
2026-10-25 feat(uart): zprovozneni realneho obousmerneho UARTu mezi ESP deskami a oprava light sleepu
2026-10-25 fix(buttons): sjednoceni mapovani tlacitek D-Pad (Up, Down, Left, Right) na obou panelech a v hrach
2026-10-30 opraveny encoder
2026-11-03 ledka na barevnym se vypina
2026-11-12 Aktualizace schemat v KiCadu a PDF dokumentace
2026-11-13 oprava os gyro mod
